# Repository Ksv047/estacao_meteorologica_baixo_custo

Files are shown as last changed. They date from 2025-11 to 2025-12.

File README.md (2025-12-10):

# 🌦️ Estação Meteorológica 3D de Baixo Custo – IFC Camboriú

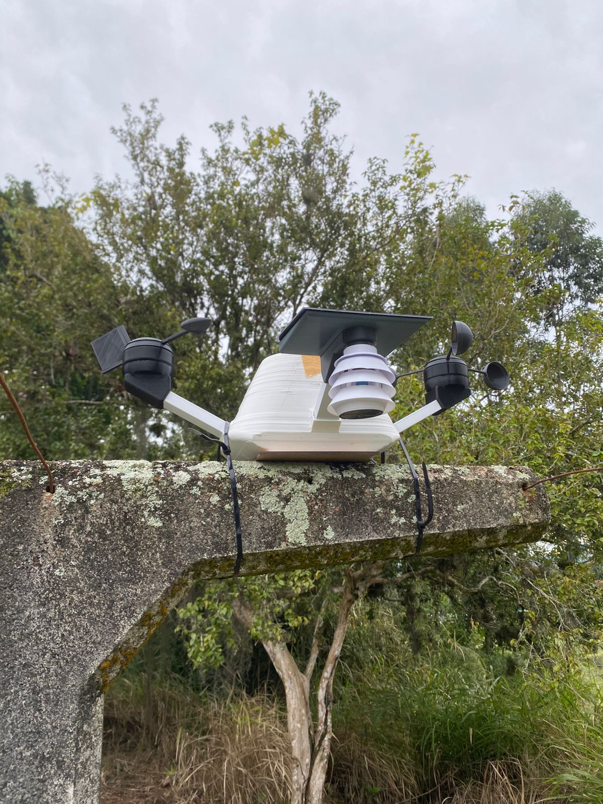
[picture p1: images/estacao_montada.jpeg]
Estação montada


##  Sobre o Projeto

Este projeto apresenta a **evolução de um protótipo de estação meteorológica de baixo custo**, desenvolvido no **Instituto Federal Catarinense - Campus Camboriú**, com o objetivo de funcionar de forma contínua em ambientes externos. 

A proposta é criar uma estação **acessível, precisa e replicável**, utilizando **impressão 3D**, **componentes eletrônicos de baixo custo** e **tecnologias IoT**, permitindo o monitoramento climático em tempo real.

---

##  Equipe de Desenvolvimento

- **Rafael Luiz C. Santos Pereira**
- **Cauã da Costa Silva**
- **Rafael de Moura Speroni** (Orientador)
- **Angelo Augusto Frozza** (Colaborador)
- **Joice Seleme Mota** (Colaboradora)

📍 *Instituto Federal Catarinense – Campus Camboriú*

---

## ⚙️ Componentes Principais

| Componente | Função |
|---|---|
| ESP32 | Microcontrolador principal |
| BME280 | Temperatura, umidade e pressão |
| AS5600 | Sensor de direção do vento |
| Reed Switch | Pluviômetro tipo báscula |
| Painel solar + bateria | Alimentação autônoma |
| PCB personalizada | Integra ESP32, sensores e monitoramento de carga |

---

##  Estrutura Física

A estrutura foi impressa em 3D e desenhada para:
- Resistir à chuva e ventos;
- Ser montada por encaixe e rosca;
- Reduzir o número de partes e o tempo de impressão;
- Permitir fixação em haste de suporte;

Arquivos STL disponíveis em [`3d_models`](hardware/3D_MODELS).

---

## 📡 Comunicação

A estação utiliza comunicação **Wi-Fi** para envio de dados ao **ThingsBoard** por meio de requisições HTTP.  
Futuramente, está prevista a integração com **LoRa (SX1278)**, visando maior alcance e menor consumo energético.

Mais informações em [`docs/comunicacao.md`](firmware/Thinsboard/thingsboard.http).

---

## 🧠 Firmware

O código-fonte está em [`firmware/src`](firmware/main/codigo_estacao.ino).

Funções principais:
- Leitura dos sensores (BME280, AS5600, reed switch);
- Cálculo de chuva e vento;
- Envio de dados via HTTP;
- Modo de sono para economia de energia (deepsleep).

---

## 📊 Exemplo de Dados

| Data | Temperatura (°C) | Umidade (%) | Pressão (hPa) | Chuva (mm) |
|---|---|---|---|---|
| 15/10/2025 10:00 | 27.3 | 68 | 1012 | 0.0 |
| 15/10/2025 11:00 | 28.1 | 66 | 1011 | 0.2 |

Mais exemplos em [`data/exemplos_medicoes.csv`](data/painel_thingsboard.png)

---

## 🤝 Contribuindo

Este projeto é de caráter **acadêmico e experimental**, parte da Feira de Iniciação Científica e Extensão (FICE 2025).  
Contribuições futuras são bem-vindas por meio de *pull requests* ou *issues*.

---

## 📸 Créditos

Projeto desenvolvido pelos alunos e professores do **IFC – Campus Camboriú**, no contexto do projeto *Plataforma georreferenciada VigiAA - Vigilância do Aedes Aegypti* (Edital FAPESC 37/2024).

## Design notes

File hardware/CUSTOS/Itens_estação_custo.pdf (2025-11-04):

A tabela a seguir apresenta o custo estimado para a confecção de uma estação meteorológica de baixo custo, conforme projeto desenvolvido no IFMaker, do IFC-Camboriú Os valores são estimados, uma vez que as estações desenvolvidas neste projeto ainda se encontram em fase de prototipação e ajustes. Além disso, os valores de alguns itens são estimados de acordo com a apresentação para compra.

Item | Descrição | Quantidade | Preço unitário | Preço total
Imã Neodinio Pequeno 2mm/3mm | Utilizado no anemômetro, pluviômetro, e sensor de direção do vento | 03 | R$ 0,20 | R$ 0,60
Reed Switch 14mm 2mm diam | Utilizado no anemômetro, pluviômetro, e sensor de direção do vento | 10 | R$ 2,00 | R$ 20,00
Eixo Metalico 6cm/0.5mm | Utilizado no anemômetro, pluviômetro, e sensor de direção do vento | 3 | R$ 9,00 | R$ 27,00
Rolamentos Mr85zz | Utilizado no anemômetro, pluviômetro, e sensor de direção do vento | 4 | R$ 6,80 | R$ 27,20
Conector Femea 2mm PHF4 03 vias | Fixação nas placas eletrônicas | 11 | R$ 0,20 | R$ 2,20
Conector Macho 2mm 90 - PHMN4 - 03 Vias | Conexão sensor/chicote/placa | 11 | R$ 0,51 | R$ 5,61
Fio Vermelho Awg24 | Chicotes Sensor/Interface | 3 | R$ 1,20 | R$ 3,60
Fio Amarelo Awg24 | Chicotes Sensor/Interface | 3 | R$ 1,20 | R$ 3,60
Fio Azul Awg24 | Chicotes Sensor/Interface | 3 | R$ 1,20 | R$ 3,60
Placa de prototipação de fenolite - 5x7cm | Placas eletrônicas e interfaces | 2 | R$ 3,00 | R$ 6,00
ESP32 Wifi DevKit1 | Microcontrolador | 1 | R$ 40,00 | R$ 40,00
Resistor 330r | Circuitos elétricos | 10 | R$ 0,14 | R$ 1,40
Resitor 200R | Circuitos elétricos | 1 | R$ 0,29 | R$ 0,29
Cabo par trançado UTP - metro | Circuitos elétricos | 1 | R$ 1,00 | R$ 1,00
18650 Battery Shield | Carregador de bateria | 1 | R$ 70,00 | R$ 70,00

Bateria 18650 3,7v’ | Alimentação | 2 | R$ 10,00 | R$ 20,00
Sensor BME280 | Sensor de pressão atmosférica | 1 | R$ 35,00 | R$ 35,00
Sensor DHT11 | Sensor de temperatura | 1 | R$ 18,00 | R$ 18,00
Filamento PLA 1,75mm | Impressão das partes estruturais da estação | 1 | R$ 100,00 | R$ 100,00

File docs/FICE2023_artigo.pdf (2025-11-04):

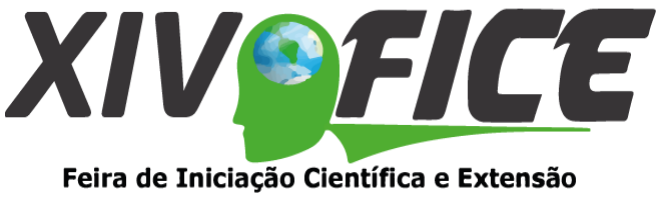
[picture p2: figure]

Desenvolvimento de uma estação meteorológica de baixo custo para mapeamento de microclima

Categoria Pesquisa
Trabalho em Andamento
Nível Graduação

Arthur Grandi¹

; Paulo Vinícius Kuss²

; Rafael Speroni³

; Daniel Anderle⁴

RESUMO

Santa Catarina é uma das regiões do Brasil mais propensas a enfrentar desastres naturais, como enchentes, deslizamentos de terra, ciclones extratropicais e até mesmo ocorrência de furacões. Dada essa vulnerabilidade, a previsão precisa do clima e o monitoramento do microclima tornam-se cada vez mais cruciais para garantir a segurança da população e reduzir os danos causados por esses eventos. O objetivo deste projeto de pesquisa é desenvolver uma estação meteorológica de baixo custo e de código aberto, que seja modular, escalável e capaz de medir indicadores de microclima. A intenção é criar uma ferramenta acessível e versátil para utilização em diversas aplicações, incluindo pesquisa científica, agricultura, monitoramento ambiental e prevenção de desastres naturais em Santa Catarina.

Palavras-chave: Estação Meteorológica; Desastres Naturais; Microclima; Baixo custo; Impressora 3D.

### 1. INTRODUÇÃO

O relatório conjunto da Universidade Federal de Santa Catarina (UFSC), Centro de Estudos e Pesquisas em Engenharia e Defesa Civil (CEPED) e Banco Mundial sobre danos materiais e prejuízos decorrentes de desastres naturais no Brasil entre 1995 e 2019 aponta que o país sofreu danos e prejuízos totais de 333,35 bilhões de reais nesse período, com uma média anual de 13,33 bilhões de reais. Santa Catarina é destacado como um estado sensível a esses desastres e aparece no topo das pesquisas em várias categorias.

De acordo com o Atlas de Desastres Naturais do Estado de Santa Catarina, entre 1980 e 2007, os dez municípios mais afetados pelo estado registraram diversos

4 Professor orientador, Instituto Federal Catarinense - Campus Camboriú, e-mail daniel.anderle@ifc.edu.br

3 Coordenador adjunto, Instituto Federal Catarinense - Campus Camboriú, e-mail rafael.speroni@ifc.edu.br

2 Estudante do curso BSI, Instituto Federal Catarinense - Campus Camboriú, e-mail paulov@kuss.com.br

1 Estudante do curso BSI, Instituto Federal Catarinense - Campus Camboriú, e-mail arthuragrandi@gmail.com eventos, como inundações graduais, inundações bruscas, escorregamentos, estiagens, granizos, vendavais, tornados e marés de tempestades. O Furacão Catarina foi um episódio inédito em 2004. Enchentes históricas em Tubarão e Blumenau causaram grandes prejuízos e impactos sociais. As enchentes em Santa Catarina frequentemente causam deslizamentos, como o ocorrido em 2008 no complexo do Morro do Baú, em Ilhota. Em 2011, as chuvas provocaram enchentes em cerca de 83 municípios, resultando em seis mortes e afetando quase 1 milhão de pessoas.

Em 2020, eventos meteorológicos extremos causaram perdas humanas e materiais em Santa Catarina, com o estado batendo recordes em números de eventos desse tipo. O relatório de danos materiais e prejuízos decorrentes de desastres naturais indica que o estado é o terceiro com mais registros de danos em ensino, totalizando um prejuízo de 163,9 milhões de reais. Em dezembro de 2022, fortes chuvas causaram alagamentos, deslizamentos e interditaram rodovias na Grande Florianópolis e outras regiões de SC, causando danos materiais e perda de vidas humanas e animais. A BR-376 foi bloqueada devido a um deslizamento de terra, isolando parcialmente o estado.

Esses desastres naturais têm ocasionado a destruição de edificações,
infraestruturas | públicas, | telecomunicações | e | danos | materiais | diversos,
representando risco à integridade física das pessoas nas áreas afetadas. O prejuízo acumulado em Santa Catarina já alcança 17,7 bilhões de reais, de acordo com o relatório de danos materiais e prejuízos decorrentes de desastres naturais. Nesse contexto, torna-se crucial estudar os microclimas e ampliar o número de estações meteorológicas como medida de redução de riscos.

O desenvolvimento de um protótipo de estação meteorológica modular de código aberto e baixo custo tem como objetivo coletar dados e medir indicadores do microclima. Os estudantes envolvidos no projeto terão a oportunidade de adquirir conhecimentos técnicos e tecnológicos, incluindo a coleta de dados e redação de artigos científicos. A integração do projeto ao Laboratório LabMaker do Campus Camboriú do IFC busca otimizar recursos e proporcionar novas oportunidades de ensino, pesquisa e extensão à comunidade acadêmica.(SANTA CATARINA e Relatório de danos materiais e prejuízos decorrentes de desastres naturais no Brasil)

### 2. PROCEDIMENTOS METODOLÓGICOS

A abordagem empregada é da pesquisa quantitativa onde a ideia é obter informações objetivas e mensuráveis, permitindo a análise estatística dos resultados para identificar padrões, relações e tendências. A pesquisa se caracteriza por uma pesquisa tecnológica, pois segundo Junior et. al(2014), o conhecimento científico, se propõe a desenvolver teorias de ampla aplicação, enquanto que o conhecimento tecnológico é responsável pelo desenvolvimento de teorias de aplicação extremamente restritas, com vistas à solução de problemas pontuais e na maioria das vezes isolados, mais voltados à inovação tecnológica.

O desenvolvimento das estações meteorológicas de baixo custo baseia-se na utilização de plataformas de hardware e softwares livres, além da utilização de componentes confeccionados em impressoras 3D. O desenvolvimento da estação meteorológica será alicerçado em uma metodologia colaborativa de projetos. Para tal implica na participação de todos os membros da equipe desde o planejamento até a execução, discutindo em grupo a viabilidade de cada uma das etapas da pesquisa.

Como ponto de partida deste projeto serão estudadas as plataformas de hardware livre Arduíno e Raspberry Pi, pois a utilização destas plataformas de forma independente ou interconectadas possibilitam a integração com diversos componentes de hardware, tais como LEDs, mostradores de matriz de pontos, botões, interruptores, motores, sensores de temperatura, pressão, de distância, de luminosidade, receptores GPS, módulos Ethernet ou qualquer outro dispositivo que emita dados ou possa ser controlado.

### 3. RESULTADOS E DISCUSSÃO

1) Climatologia

A climatologia estuda variáveis como temperatura, precipitação, vento, umidade, pressão atmosférica, radiação solar, entre outros, para compreender as condições climáticas de uma região. Além disso, a climatologia também investiga as causas das mudanças climáticas, incluindo os impactos humanos e naturais sobre o clima. A compreensão do clima é crucial para muitas atividades humanas, incluindo agricultura, gestão de recursos hídricos, prevenção de desastres naturais e planejamento urbano, entre outras.
Segundo Steinke(2016), entender a climatologia requer uma compreensão básica dos controles físicos do clima, essencialmente os fatores astronômicos e fatores terrestres que juntos determinam a natureza dos climas na terra ao longo do tempo. Os fatores são agentes causais que condicionam os elementos climáticos(radiação solar, temperatura do ar, umidade do ar, pressão atmosférica, velocidade e direção do vento, tipo e quantidade de precipitação. A atuação desses diversos fatores faz com que os elementos climáticos, e meteorológicos, variem no espaço e no tempo.

Ainda nesse contexto, podemos reduzir os climas, que ocupam grandes áreas, em partes menores. Na climatologia eles são denominados microclimas.

1.1 Microclima

O microclima é o clima local de uma área específica, que pode diferir do clima regional ou global. É influenciado por fatores como topografia, presença de corpos d' água, vegetação, material de construção, entre outros. O microclima é importante porque pode afetar a vida selvagem, a agricultura e a saúde humana.
Monteiro e Mendonça (2003) descrevem o microclima como a formação de condições climáticas na escala intra-urbana, derivadas diretamente da heterogeneidade, tanto do sítio, quanto da estruturação, morfologia e funcionalidades urbanas, gerando, paralelamente ao clima da cidade, bolsões climáticos intra-urbanos diferenciados, como ilhas de calor, topoclimas e microclimas.
Por isso, a medição precisa do microclima é importante para compreender as condições locais e como elas podem afetar a vida, a agricultura, as cidades e até mesmo a saúde humana.
2) Hardware

Segundo Da Silva et al.(2016), para construir uma estação meteorológica de baixo custo, é necessário selecionar hardware que seja acessível, confiável e capaz de realizar as medições necessárias. Alguns dos componentes comuns que podem ser usados incluem: Sensores: É necessário escolher sensores para medir as variáveis climáticas desejadas, como temperatura, umidade, pressão atmosférica, quantidade de precipitação, entre outros. Microcontrolador: Este componente é responsável por coletar e processar os dados dos sensores. Alguns microcontroladores populares para uso em projetos de baixo custo incluem o Arduino e o Raspberry Pi. Display: É importante ter uma forma de visualizar os dados coletados. Isso pode ser feito através de um display OLED ou um computador conectado à estação meteorológica. Bateria: Se a estação meteorológica for usada em locais remotos sem acesso à energia elétrica, é necessário incluir uma bateria para alimentar o sistema. Conectividade: Para transmitir os dados coletados, é necessário incluir uma forma de conectividade, como Wi-Fi ou rede celular.

3) Software

O uso de software livre é uma excelente opção para a construção de uma estação meteorológica de baixo custo, pois oferece vários benefícios, incluindo: Acessibilidade: Como o código-fonte está disponível publicamente, é possível acessá-lo e modificá-lo livremente, o que pode ser útil para personalizar a estação meteorológica para atender às necessidades específicas do projeto. Comunidade: Muitos projetos de software livre têm uma comunidade ativa de desenvolvedores e usuários, o que significa que há muitos recursos e soluções disponíveis para problemas comuns. Economia: Como o software livre é gratuito, pode ser uma ótima opção para projetos de baixo orçamento, onde é necessário minimizar os custos. Flexibilidade: Como o software livre é open-source, é possível modificá-lo para atender às necessidades específicas do projeto, o que é importante em projetos de estação meteorológica, onde é necessário medir variáveis climáticas específicas. Integração: O software livre pode ser facilmente integrado com outros componentes da estação meteorológica, como sensores, microcontroladores e displays.
Alguns exemplos de software livre que podem ser usados na construção de uma estação meteorológica de baixo custo incluem o OpenWeatherMap, o WeeWX e o PyOWM. A escolha exata do software dependerá das necessidades específicas do projeto e da experiência dos desenvolvedores.
4) Impressora 3D e as Estações Meteorológicas

Customização: As impressoras 3D permitem a impressão de peças personalizadas, o que é importante em projetos de estações meteorológicas, onde é necessário medir variáveis climáticas específicas. Redução de custos: Ao utilizar impressoras 3D, é possível reduzir os custos de fabricação de componentes, como suportes para sensores, caixas de proteção e outros componentes. Prototipagem rápida: As impressoras 3D permitem a produção de protótipos rapidamente, o que é importante no desenvolvimento de projetos de estações meteorológicas, onde é necessário testar e ajustar os componentes antes da construção final. Versatilidade: As impressoras 3D podem ser usadas para imprimir componentes de diferentes materiais, incluindo plásticos, resinas e metais, o que oferece muita flexibilidade na construção de componentes para a estação meteorológica. Acessibilidade: Com a popularidade das impressoras 3D, elas estão ficando cada vez mais acessíveis e fáceis de usar, o que significa que é possível imprimir componentes sem precisar de muita habilidade técnica.(DE JESUS QUEIROZ, MAURICIO e MATRAKAS,2019)

Em suma, as impressoras 3D podem ser uma ferramenta valiosa para a construção de um protótipo de uma estação meteorológica de baixo custo, pois permitem a produção de componentes personalizados, a redução de custos, a prototipagem rápida, a versatilidade e a acessibilidade

5) Resultados Parciais.

Com base no intuito de ser um projeto de baixo custo, os componentes da estação responsáveis pelas medições e análises climáticas foram selecionados de fontes abertas em plataformas de compartilhamento de projetos e produzidas nas impressoras 3D do IF Maker.

Com essa etapa concluída partimos para a seleção de qual microcontrolador será utilizado na estação meteorológica. Estudos foram feitos comparando a praticidade do arduino mega que não possui conexão wifi acoplada ao do esp 32 que conta com módulo wifi. Fica evidente além do custo mais baixo do esp 32 a praticidade que ele fornece ao possibilitar uma conexão direta a rede wifi.

Os testes seguirão para confirmar aspectos de outros componentes do projeto até que após a conclusão dos testes o protótipo seja finalizado, permitindo seguir para as análises comparativas entre custo benefício e eficiência da nossa estação e das estações comerciais.

6) Resultados Esperados

Desenvolver o protótipo de uma estação meteorológica modular de código aberto de baixo custo, para coleta de dados e medição de indicadores do microclima.

- Desenvolver o protótipo de um estação meteorológica utilizando componentes eletrônicos de baixo custo e partes desenvolvidas em uma impressora 3D do laboratório IFMaker do IFC - Campus Camboriú;
- Desenvolver uma aplicação para medir temperatura, umidade relativa do ar, pressão atmosférica, velocidade do vento e precipitação pluviométrica;
- Desenvolver um sistema para coleta dos dados meteorológicos de forma automatizada;
- Testar a viabilidade técnica da estação meteorológica através de testes e comparações com estações meteorológicas já aferidas;
- Comparar o custo do protótipo desenvolvido com estações meteorológicas comerciais;

### 4. CONSIDERAÇÕES FINAIS

Com o projeto intuímos trazer a educação climática para dentro das escolas de forma prática, ensinando os jovens a necessidade de estarem atentos às mudanças climáticas na sua região para a segurança de suas famílias e suas comunidades. Esse acesso também abre oportunidades de educação e integração no mundo da tecnologia por demonstrar a conexão entre a análise de dados, os sistemas de informação e a vida cotidiana.

Unificando os estudos, os testes e toda a pesquisa realizada, identificou-se uma lacuna para o crescimento da cobertura meteorológica no brasil e principalmente nos estados que são mais vulneráveis a catástrofes climáticas. A pesquisa tecnológica visa a implementação de uma solução para um problema específico. Nosso alvo, o problema das perdas humanas e materiais causados pela devastação de desastres climáticos e ambientais. O aumento no número de estações meteorológicas têm o potencial de preparar o poder público e a população para potenciais desastres, diminuindo os riscos à vida humana. Importante salientar que através do estudo dos microclimas será possível planejar o crescimento seguro da área urbana, impedindo a formação das ilhas de calor, reduzindo a quantidade da população que vive em áreas com risco de enchente, dentre outras formas de prevenção que um planejamento urbano e climático pode proporcionar.

### 5. REFERÊNCIAS

DA SILVA, Angelo Cesar Mendes, et al. ESTAÇÃO METEOROLÓGICA AUTOMÁTICA DE BAIXO CUSTO-Low Cost Automatic Meteorological Station. Multiverso: Revista Eletrônica do Campus Juiz de Fora-IF Sudeste MG, 2016, 1.1: 46-56.

DE JESUS QUEIROZ, Leonardo; MAURICIO, Claudio Roberto Marquetto; MATRAKAS, Miguel Diogenes. Construção de uma impressora 3D: Projetos abertos de baixo custo e possibilidades da aplicação na educação. 2019.

EPAGRI -Empresa de Pesquisa Agropecuária e Extensão Rural de Santa Catarina . Eventos meteorológicos bateram recordes em Santa Catarina em 2020. Disponível em:
<https://www.epagri.sc.gov.br/index.php/2021/01/27/eventos-meteorologicos-bateram-recordes-em-santa-catarina-em-2020/>. Acesso em: 12 dez. 2022.

FREITAS JUNIOR, Vanderlei., et al. A pesquisa científica e tecnológica. Revista Espacios, vol. 35, nº 9, 2014. Disponível em: https://www.revistaespacios.com/a14v35n09/14350913.html. Acesso em: 04 de setembro de 2023.

IBGE - Instituto Brasileiro de Geografia e Estatística. Cidades e Estados. Disponível em: <https://www.ibge.gov.br/cidades-e-estados/sc.html>. Acesso em: 12 dez. 2022.

MONTEIRO, C. A. F.; MENDONÇA, F. (org.) Clima urbano. 2ª edição, São Paulo: Contexto, 2015. 191p

Relatório de danos materiais e prejuízos decorrentes de desastres naturais no Brasil : 1995 – 2019 / Banco Mundial. Global Facility for Disaster Reduction and Recovery. Fundação de Amparo à Pesquisa e Extensão Universitária. Centro de Estudos e Pesquisas em Engenharia e Defesa Civil. [Organização Rafael Schadeck] – 2. ed. – Florianópolis: FAPEU, 2020. 156 p. : il. color.; 30 cm.

SANTA CATARINA. Atlas de desastres naturais do estado de santa catarina: período de 1980 a 2010. IHGSC/Cadernos Geográficos, 2014, 2.

STEINKE, Ercília Torres. Climatologia fácil. Oficina de Textos, 2016.

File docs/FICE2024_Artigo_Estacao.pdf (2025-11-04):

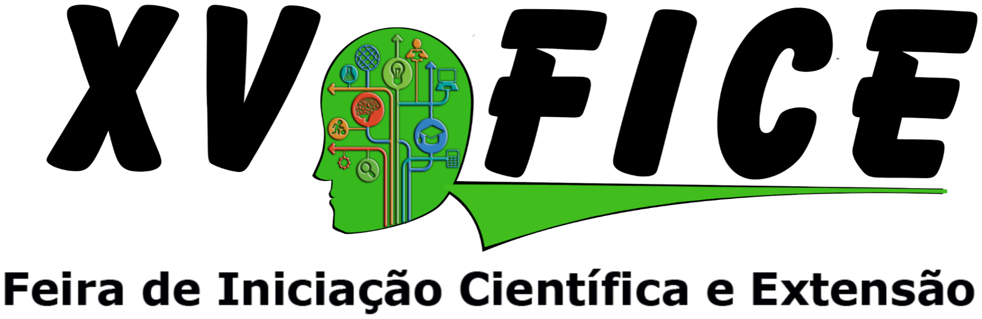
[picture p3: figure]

Desenvolvimento de uma Estação Meteorológica de Baixo Custo - Fase II

Categoria: Pesquisa
Trabalho: Trabalho em Andamento Nível: Graduação

Rafael Luiz C. Santos Pereira¹

; Paulo Vinícius Kuss²
; Rafael de Moura
Speroni³Daniel Fernando Anderle⁴

RESUMO

O trabalho descreve a segunda fase do projeto que tem por finalidade o desenvolvimento de uma estação meteorológica de baixo custo, caracterizada como um dispositivo de internet das coisas (IoT). Tendo como ponto de partida um protótipo desenvolvido com projeto de código aberto, a segunda fase tem por objetivo a otimização das estruturas, visando ao projeto e construção de um equipamento mais compacto, bem como da substituição de circuitos e componentes eletrônicos. Por meio da comparação com uma solução comercial, identificou-se a necessidade de alterações em componentes de hardware, bem como de ajustes nos códigos-fonte responsáveis pela coleta e envio dos dados. Atualmente, encontra-se em fase de construção do segundo protótipo, já incluindo as melhorias.

Palavras-chave: estação meteorológica; internet das coisas; clima.

### 1. INTRODUÇÃO

Segundo o Atlas Digital de Desastres no Brasil (Brasil, 2023), no ano de 2023, o estado de Santa Catarina registrou 386 ocorrências de eventos climáticos extremos, resultando em graves consequências. Esses eventos afetaram diretamente 1.346.345 pessoas, deixando 98.428 desabrigados e desalojados. Os danos materiais foram avaliados em R$1.6 Bi, enquanto os prejuízos totais atingiram a cifra de R$3.48 Bi, além de resultar em 10 óbitos. Esses eventos, classificados como de origem hidrológica (inundações, alagamentos, enchentes, deslizamentos) e meteorológica (raios, ciclones, tornados, vendavais), evidenciam a vulnerabilidade da região frente aos eventos climáticos extremos.
Diante desse cenário torna-se evidente, a importância de uma rede de estações meteorológicas conectadas e inteligentes para a prevenção e o alerta antecipado que potencialmente podem salvar vidas e minimizar os riscos de perdas humanas e materiais. Nos últimos 10 anos, Santa Catarina registrou 32 óbitos decorrentes de eventos climáticos de origem hidrológica, conforme indicado pelo Atlas Digital de Desastres no Brasil (Brasil, 2023).
A Internet das Coisas (IoT) é um conceito que ainda está em evolução, sem uma definição fixa e amplamente aceita. Segundo Mouha (2021), a IoT continua a

4 Professor orientador, IFC Camboriú, daniel.anderle@ifc.edu.br

3 Professor orientador, IFC Camboriú, rafael.speroni@ifc.edu.br

2 Estudante do curso BSI, Instituto Federal Catarinense - Campus Camboriú, e-mail pviniks@gmail.com

1 Estudante do curso de Bacharelado em Sistemas de Informação, IFC Camboriú, rafaelluizcc@gmail.com -bolsista - Edital 12/2024 amadurecer, sendo um dos conceitos mais novos e populares no mundo da tecnologia da informação. A essência da IoT está na ideia de "coisas" — qualquer dispositivo equipado com sensores embutidos, capaz de coletar dados e transmiti-los por meio de redes sem a necessidade de intervenção humana. A tecnologia incorporada nesses dispositivos permite que eles interajam tanto com seu estado interno quanto com o ambiente externo, auxiliando no processo de tomada de decisões.
Nesse contexto, a tecnologia IoT tem o potencial de desempenhar um papel vital na prevenção de perdas humanas durante desastres. Ao utilizar estações meteorológicas de baixo custo conectadas, a tecnologia IoT pode ajudar a prever situações de risco analisando a meteorologia e em casos de risco, emitindo alertas antecipados, possibilitando uma resposta rápida e eficaz para minimizar os impactos de eventos climáticos extremos. Assim, a tecnologia pode ser uma aliada poderosa na mitigação de desastres, salvando vidas e reduzindo prejuízos.
A implantação de uma estação meteorológica oferece diversas vantagens, mas um dos obstáculos à sua popularização e uso em larga escala é o custo. As alternativas mais baratas de estações meteorológicas comerciais têm seu preço aproximado iniciando em R$2.500,00⁵
, enquanto que o custo estimado para a fabricação deste protótipo, é de aproximadamente R$440,00. O desenvolvimento de uma estação meteorológica de baixo custo no campus IFC Camboriú⁶ é benéfico para toda a comunidade do Instituto Federal, pois promove a criação de uma tecnologia acessível com múltiplas aplicações, desde o uso agrícola até a prevenção de desastres naturais.
As tecnologias open source foram essenciais no desenvolvimento da estação meteorológica de baixo custo. Essa tecnologia permite que usuários modifiquem e adaptem ferramentas sem custos, oferecendo flexibilidade e acessibilidade no desenvolvimento. Um exemplo é a tecnologia da placa ESP32, de hardware aberto. A natureza open source dessas ferramentas acelerou o progresso do projeto, permitindo o uso de diversos recursos sem restrições financeiras.
No trabalho anterior, intitulado "Desenvolvimento de uma Estação Meteorológica de Baixo Custo para Mapeamento de Microclima" (Grandi et al., 2023), foi discutido o desenvolvimento de um protótipo para demonstração da tecnologia e para estudos de viabilidade. Com o avanço desse projeto, na segunda versão, está em desenvolvimento uma estação meteorológica independente com estrutura compacta, capaz de ser instalada em ambientes externos. Este novo modelo visa oferecer um baixo custo, mas com funcionalidades semelhantes às das estações meteorológicas comerciais, proporcionando uma solução prática e acessível para o monitoramento climático.

### 2. PROCEDIMENTOS METODOLÓGICOS

Para o desenvolvimento do trabalho está sendo realizada a pesquisa bibliográfica, segundo a qual se faz a revisão da literatura relacionada à temática. Nesta abordagem, a resolução de um problema é buscada por meio da análise dos referenciais teóricos e suas contribuições (Boccato, 2006).
A pesquisa se caracteriza como Tecnológica (Freitas Júnior et. al, 2014), uma vez que o conhecimento tecnológico é responsável pelo desenvolvimento de teorias de aplicação extremamente restritas, com vistas à solução de problemas pontuais e

6 Projeto aprovado no Edital 12/2024 – Apoio a Projetos de Pesquisa no Laboratório IFMaker

5 Pesquisa de preço realizada em sites no Brasil.

na maioria das vezes isolados, mais voltados à inovação tecnológica. Para Cupani (2006), o conhecimento tecnológico, estando dirigido a uma tarefa específica, tem como resultado tipos de soluções para determinadas aplicações.
A revisão de literatura ocorre em paralelo com as demais etapas do projeto, em função da necessidade de compreensão de conceitos e da identificação de técnicas específicas a serem utilizadas.
Partiu-se de um primeiro protótipo, desenvolvido na edição anterior do projeto (Grandi et al., 2023), cujas peças estruturais foram impressas em impressoras 3D, a partir de projeto de código aberto (Ward, 2018), e o módulo eletrônico foi baseado em uma placa ESP32, um conjunto de microprocessadores de baixo custo, compatível com diversos tipos de sensores.
A etapa seguinte teve por objetivo integrar o protótipo desenvolvido com um serviço de coleta, armazenamento e visualização de dados⁷
. Para tal, utilizou-se o
servidor de IoT Thingsboard (2024), disponível na infraestrutura do IFMaker do IFC-Camboriú. Este servidor conta com uma lnterface de Programação de Aplicação (API) Restful, e os dados são enviados pela estação meteorológica por meio de requisições HTTP.
Visando à identificação das necessidades de melhorias na estação projetada, as medidas coletadas a partir dos sensores do protótipo foram comparadas com as medidas obtidas pela estação meteorológica do Curso Técnico em Defesa Civil do IFC-Camboriú⁸
, que trata-se de um modelo comercial. A partir desta comparação, identificou-se uma inconsistência nos cálculos do pluviômetro e do anemômetro, para os quais se buscou a correção.
Visando aos ajustes de medidas, passou-se à alteração de componentes estruturais da estação. Assim, projetou-se uma nova versão para o chassi principal, mais compacta, e que permita uma melhor fixação em uma haste. Além disso, houve necessidade de reprojetar o anemômetro, uma vez que o primeiro modelo estava pouco sensível. Foram feitos os desenhos técnicos auxiliados por computador, com a posterior modelagem 3D e exportação para formato compatível com as impressoras 3D.
Atualmente, ainda está em desenvolvimento a nova versão do anemômetro, bem como busca-se otimizar a solução da alimentação da estação, com o uso de painéis de energia solar e baterias. O objetivo é garantir a autonomia do equipamento, de forma que seja capaz de funcionar de forma ininterrupta.
A próxima seção descreve em mais detalhes os componentes da estação, além de apresentar alguns dos artefatos gerados no processo de desenho técnico e modelagem do novo protótipo.

### 3. RESULTADOS E DISCUSSÃO

O protótipo resultante da Fase 1 do projeto tem uma estrutura cuja finalidade era possibilitar a demonstração dos componentes, e o circuito eletrônico foi montado de maneira provisória, utilizando-se uma placa de ensaio (protoboard), conforme foto apresentada na figura 1.

8 Painel da Estação Meteorológica do TDC: https://ambientweather.net/dashboard/60a4f7e92df2960cb08d2a92a3607a94

7Painel de visualização das medidas da Estação desenvolvida: https://abre.ai/estacaoifmaker

Figura 1 - Estação Meteorológica: Protótipo da Fase 1 do projeto

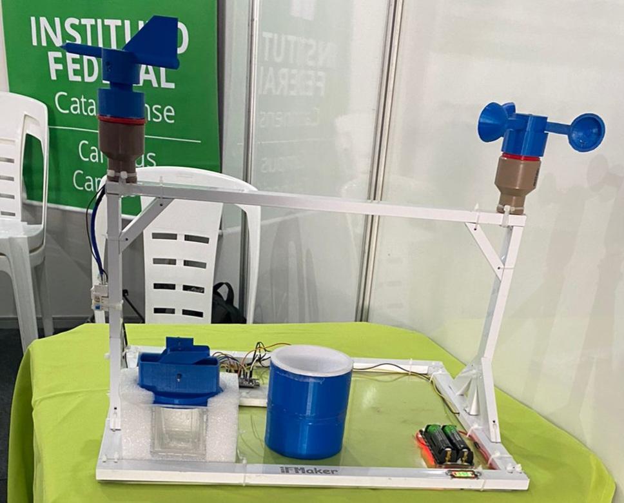
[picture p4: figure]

Fonte: Elaborado pelos autores
O funcionamento do pluviômetro é baseado no princípio de medição de volume coletado. Conforme a água da chuva desce por um funil, ela é direcionada para a báscula, que funciona como uma pequena balança. Quando a báscula atinge um determinado volume de água, seu peso faz com que ela incline, o movimento é detectado por um sensor, (Mansano et al., 2015, p. 19) a precipitação é contabilizada contando o número de interações do sensor, após, os dados do sensores então são processados pela placa principal, que envia os valores para o servidor.

Figura 2 - Desenho Técnico do Pluviômetro de Báscula.

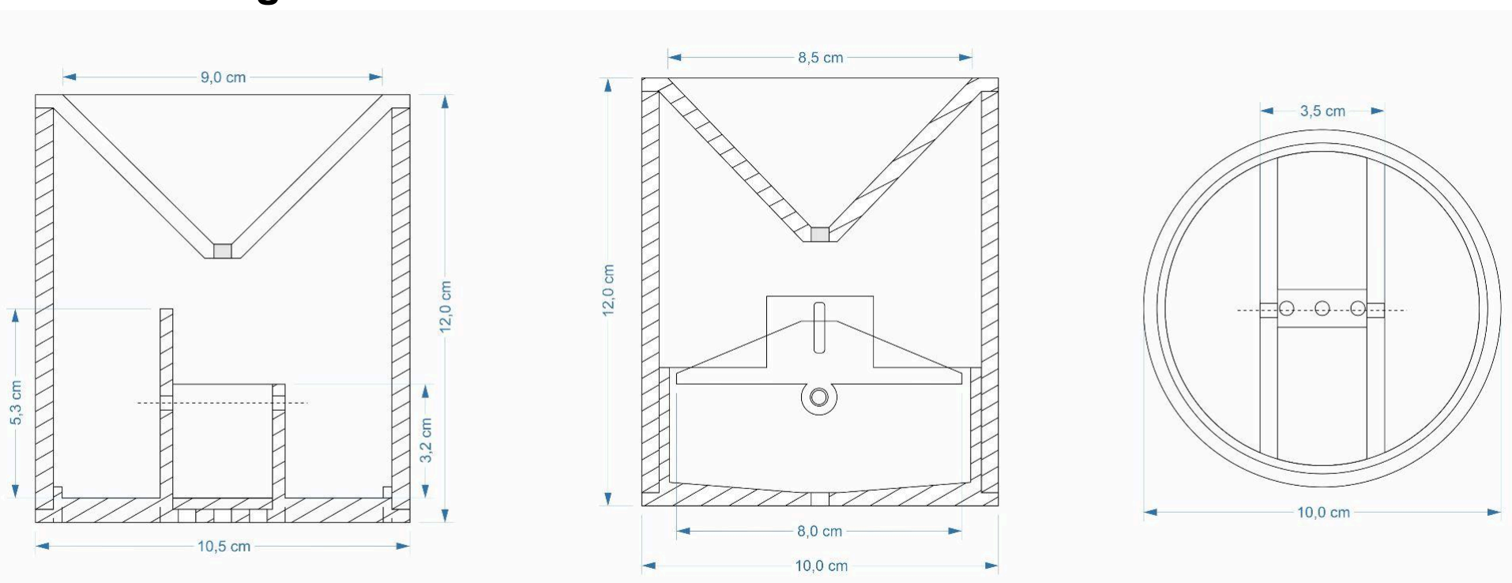
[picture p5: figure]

Fonte: Elaborado pelos autores
A Figura 2 apresenta um desenho técnico do pluviômetro, no desenho estão dispostos respectivamente, a vista lateral em corte, a vista frontal em corte, e a vista superior do pluviômetro.
O anemômetro, sensor para medir a velocidade do vento, utiliza uma hélice anemométrica conectada a um eixo metálico, que é suportado por dois rolamentos, fixos a uma base, onde está posicionado um sensor magnético (reed switch). Na estrutura da hélice foi acoplado um ímã de neodímio. Conforme a hélice gira com a força do vento, o ímã passa pelo reed switch, gerando pulsos elétricos. O sistema, então, contabiliza o número de pulsos emitidos em um determinado período, permitindo o cálculo da velocidade do vento.
Já o anemógrafo, que está montado em uma estrutura semelhante à do anemômetro, conta com uma peça móvel que muda de posição, conforme a direção do vento. A peça possui um ímã de neodímio que, ao girar, passa por 8 sensores magnéticos (reed switches), dispostos ao redor do sensor. Cada um destes sensores corresponde a um dos pontos cardeais (Norte, Sul, Leste, Oeste) e colaterais (Nordeste, Noroeste, Sudeste, Sudoeste), são acionados a depender da posição em que o ímã se encontra, gerando um sinal elétrico.
Para a medição de temperatura (termômetro) e umidade (higrômetro), o sensor escolhido foi o DHT11. Trata-se de um sensor amplamente utilizado em projetos de monitoramento ambiental devido à sua confiabilidade, simplicidade de uso, e baixo custo, e cujo princípio de funcionamento baseia-se em um termistor e um sensor capacitivo. As medidas deste sensor podem ser coletadas diretamente, sem a necessidade de cálculo ou transformação.

Figura 3 - Esquema eletrônico da Estação Meteorológica

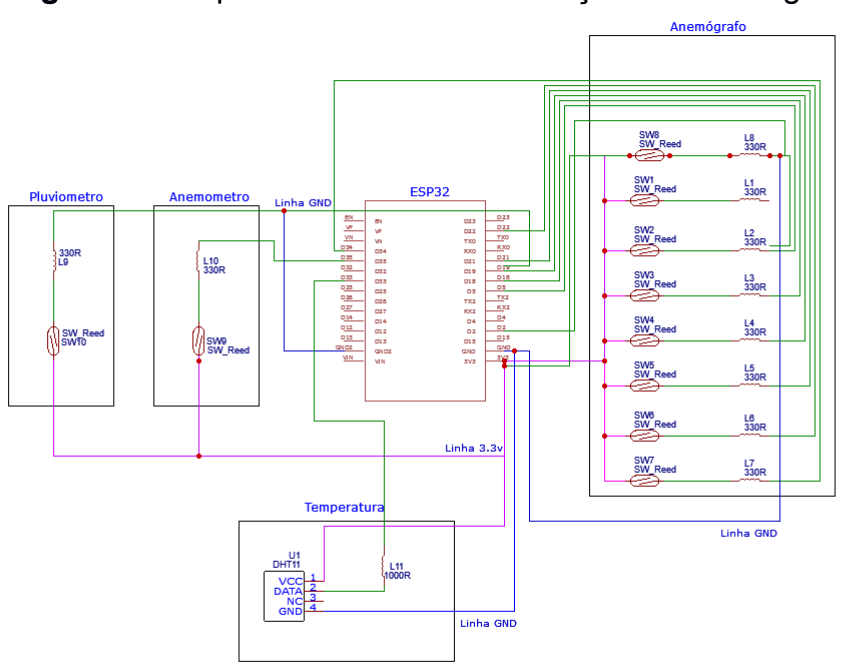
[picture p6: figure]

Fonte: Elaborado pelos autores
Na Figura 3 é apresentado o esquema elétrico da estação, a partir do diagrama eletrônico elaborado, foi desenvolvido um novo protótipo de placa eletrônica, visando à diminuição do espaço ocupado, e a utilização de conectores padronizados. Todos os componentes foram soldados em uma placa de prototipagem de 5x7cm.

Figura 4 - Estação Meteorológica: Protótipo da Fase 1 do projeto

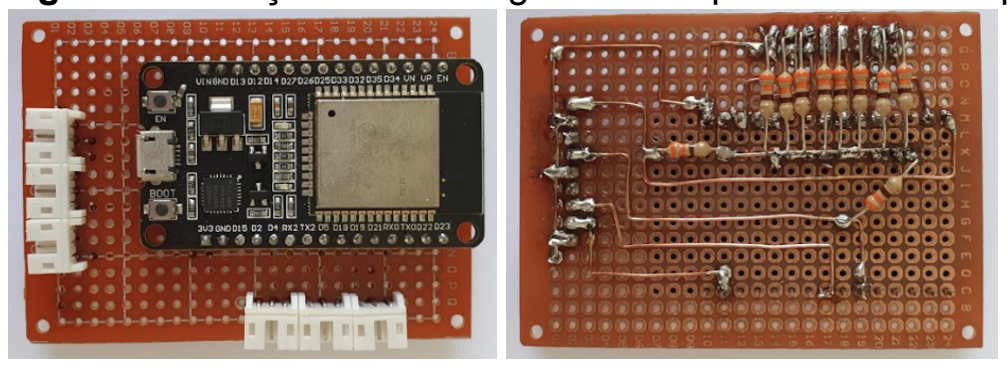
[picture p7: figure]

Fonte: Elaborado pelos autores

A Figura 4 apresenta o novo protótipo de placa eletrônica, onde é possível observar, na parte superior, a placa ESP32 e os conectores. Na parte inferior, estão localizados os resistores e fios que servem de trilhas.
A utilização de conectores justifica-se pela modularidade, de forma que cada sensor foi munido de um chicote de fios e conectores, podendo ser facilmente substituído, se necessário.
As medidas coletadas são transformadas em um conjunto de dados em formato JSON, que é enviado em uma requisição HTTP para a API do servidor de IoT. Dessa forma, os dados são agregados em um painel, que conta com diferentes gráficos e tabelas.

Figura 5 - Painel de visualização dos dados da estação meteorológica

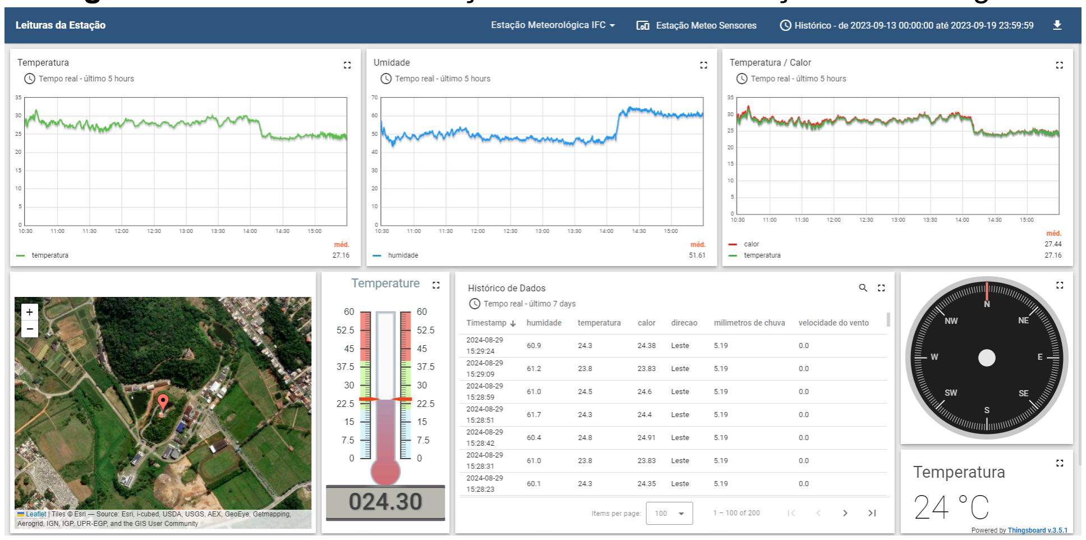
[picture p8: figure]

Fonte: Elaborado pelos autores

A Figura 5 apresenta uma captura de tela do painel de visualização das informações da estação meteorológica. Cabe salientar que, este painel é facilmente replicável para cada nova unidade de estação meteorológica que venha a ser construída, podendo-se gerar um conjunto de dados relevantes para o estudo do microclima.

### 4. CONSIDERAÇÕES FINAIS

Eventos climáticos extremos têm acontecido no mundo todo, e com frequência cada vez maior. O estado de Santa Catarina não é diferente, e vem experienciando importantes impactos sociais e econômicos, decorrentes destes eventos. Por isso, o monitoramento do clima mostra-se uma importante ferramenta na mitigação de impactos e na informação e conscientização da população.
Neste projeto, a proposta de desenvolvimento de uma estação meteorológica de baixo custo não busca competir com modelos comerciais. Antes disso, deseja-se demonstrar a viabilidade do desenvolvimento de um modelo replicável, com potencial educacional. Utilizando tecnologias de código aberto, e com a disponibilização do projeto completo, tanto sua confecção quanto a observação dos dados coletados podem ser objetos de estudo em escolas.
Ainda que o novo protótipo esteja em desenvolvimento, já é possível identificar avanços em relação à primeira fase do projeto. Desde a identificação de necessidades de melhorias em componentes do hardware impresso em 3D, passando por modificações no esquema eletrônico, até a adoção de um serviço de coleta e visualização de dados, que poderá ser utilizado por outros projetos de IoT do IFMaker.

### 5. REFERÊNCIAS

ARDUINO. About Arduino. Arduino, 2024. Disponível em: https://www.arduino.cc/en/about. Acesso em: 31 ago. 2024.

BRASIL. Ministério da Integração e do Desenvolvimento Regional. Secretaria de Proteção e Defesa Civil. Universidade Federal de Santa Catarina. Centro de Estudos e Pesquisas em Engenharia e Defesa Civil. Atlas Digital de Desastres no Brasil. Brasília: MIDR, 2023.

BOCCATO, V. R. C. Metodologia da pesquisa bibliográfica na área odontológica e o artigo científico como forma de comunicação. Revista de Odontologia da Universidade Cidade de São Paulo, São Paulo, v. 18, n. 3, p. 265-274, 2006. Disponível em
https://arquivos.cruzeirodosuleducacional.edu.br/principal/old/revista_odontologia/pdf/setembro_dezembro_2006/metodologia_pesquisa_bibliografica.pdf (https://arquivos.cruzeirodosuleducacional.edu.br/principal/old/revista_odontologia/pdf/setembro_dezembro_2006/metodologia_pesquisa_bibliografica.pdf) Acesso em 25 ago. 2024.

CUPANI, Alberto. La peculiaridad del conocimiento tecnológico. ScientiaeStudia, São Paulo, v. 4, n. 3, p. 353-71, 2006. Disponível em: http://www.scielo.br/pdf/ss/v4n3/a01v4n3.pdf. Acesso em: 06 abr. 2012.

FREITAS JUNIOR, Vanderlei., et al. A pesquisa científica e tecnológica. Revista Espacios, vol. 35, no 9, 2014. Disponível em: https://www.revistaespacios.com/a14v35n09/14350913.html. Acesso em: 25 ago. 2023.

GRANDI, Arthur; KUSS, Paulo Vinícius; SPERONI, Rafael de Moura; ANDERLE, Daniel Fernando. Desenvolvimento de uma Estação Meteorológica de Baixo Custo para Mapeamento de Microclima. In: FICE 2023, Camboriú. Anais Eletrônicos [...] Camboriú: IFC-Camboriú, 2024. Disponível em: https://publicacoes.ifc.edu.br/index.php/fice/issue/view/134. Acesso em 25 ago. 2024.

MANSANO, Matheus Veiga et al. Calibração de Pluviômetros de Báscula: Metodologia para análise e correção de dados de campo - Calibration of Tipping Bucket Rainfall Gauges: A methodology for field data analysis and correction. In: XV Safety, Health and Environment World Congress; jul. 2015. p. 19-22.

MOUHA, Radouan Ait Radouan Ait et al. Internet of things (IoT). Journal of Data Analysis and Information Processing, v. 9, n. 02, p. 77, 2021.
THINGSBOARD. ThingsBoard - Open Source IoT Platform. c2024. Página inicial. Disponível em: https://thingsboard.io. Acesso em 27 ago. 2024.

WARD, Rob. LTB Weather Station. Thinginverse. 2018. Disponível em: https://www.thingiverse.com/thing:2849562. Acesso em 27 ago. 2024.

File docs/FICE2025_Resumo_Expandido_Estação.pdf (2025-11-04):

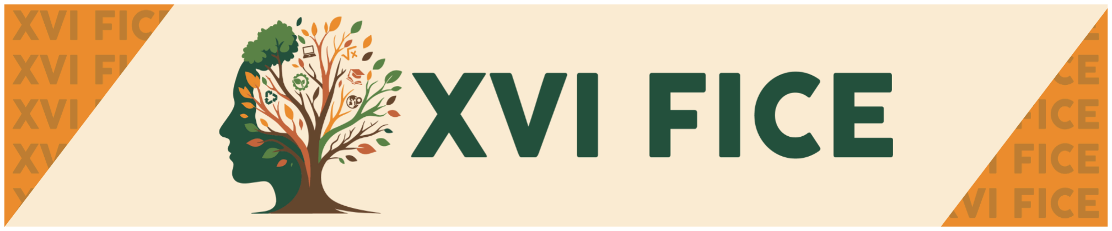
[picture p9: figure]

ESTAÇÃO METEOROLÓGICA DE BAIXO CUSTO: Resultados e desafios

Categoria: Pesquisa
Trabalho: Trabalho em Andamento Nível: Graduação

Rafael Luiz C. Santos Pereira¹

, Cauã da Costa Silva²

, Rafael de Moura Speroni³ ,
Angelo Augusto Frozza⁴

, Joice Seleme Mota⁵

RESUMO

Este trabalho apresenta a evolução de um protótipo de estação meteorológica de baixo custo desenvolvido para funcionar de forma contínua em ambientes externos. O estudo partiu de uma versão inicial e focou em aprimorar o protótipo melhorando a parte física e eletrônica. Comparações com estações meteorológicas comerciais revelaram inconsistências no sensor de chuva, o que impulsionou um redesenho da arquitetura do protótipo. A nova versão incorpora um sistema de energia solar que assegura autonomia ininterrupta, sensores mais precisos capazes de medir pressão atmosférica, temperatura, umidade, precipitação, velocidade e direção do vento e um novo código fonte. Os resultados preliminares demonstram avanços significativos comparados ao modelo anterior, com melhorias notáveis na precisão e robustez, o que garante maior confiabilidade nos dados coletados. Como perspectivas futuras busca-se aprimorar a comunicação entre os dispositivos por meio da implementação da tecnologia LoRa, visando maior eficiência e alcance. Adicionalmente, a otimização do design a tornará mais acessível para diversas aplicações no monitoramento climático.
Palavras-chave: estação meteorológica; (IoT); clima; LoRa;

### 1. INTRODUÇÃO

Segundo dados do Atlas Digital de Desastres no Brasil (Brasil, 2025) em 2024 a região sul do Brasil sofreu com eventos classificados como de origem hidrológica (inundações, alagamentos, enchentes, deslizamentos) que deixaram 189 mortos e 805.270 pessoas desabrigadas ou desalojadas. Segundo o Conselho Permanente de Agrometeorologia Aplicada do Estado do Rio Grande do Sul (COPAAERGS, 2024), no período de 27 de abril a 2 de maio (6 dias), em muitas cidades do Rio Grande do Sul, a precipitação registrada foi entre 300 e 400 mm e, em outras, os valores atingiram 500 a 700 mm, o que corresponde a um terço da média histórica de precipitação anual.
A utilização de estações meteorológicas de baixo custo baseadas em conceitos da Internet das Coisas (IoT) surge como alternativa viável para ampliar o

5 Professor colaborador, IFC Camboriú, joice.mota@ifc.edu.br

4 Professor colaborador, IFC Camboriú, | angelo.frozza@ifc.edu.br
3 Professor orientador, IFC Camboriú, | rafael.speroni@ifc.edu.br

2 Estudante do curso Bacharelado em Sistemas de informação, IFC Camboriú, caua.silva.ifc@gmail.com

1 Estudante do curso Bacharelado em Sistemas de informação, IFC Camboriú, rafaelluizcc@gmail.com alcance do monitoramento, além de ser uma solução que pode ter impacto em outras áreas. Para Freitas (2025, p. 15), o desenvolvimento de estações meteorológicas de baixo custo permite que pequenos produtores rurais, pesquisadores e demais interessados nos estudos climatológicos tenham acesso a sistemas de coleta e uso desses dados.
A Internet das Coisas (IoT) é um conceito em evolução, segundo Bruno P. Santos et al. (2016) a Internet das Coisas, em poucas palavras, nada mais é que uma extensão da Internet atual, que proporciona aos objetos do dia-a-dia com capacidade computacional e de comunicação se conectarem à Internet. Segundo Mouha (2021) a IoT continua a amadurecer, sendo um dos conceitos mais novos e populares no mundo da tecnologia da informação. Esse conceito aplicado à meteorologia possibilita o desenvolvimento de sistemas distribuídos e interconectados que coletam, processam e transmitem dados ambientais em tempo real, fornecendo informações essenciais para ações de resposta rápida e planejamento preventivo em casos de desastres.
Em ambientes urbanos e industriais o monitoramento ambiental é crucial para a gestão de recursos e a proteção da saúde pública. Como destacam Gonçalves, Freitas e Jesus (2024), estações meteorológicas de baixo custo integradas a sistemas IoT permitem a coleta de dados meteorológicos, contribuindo para a avaliação de riscos e o planejamento urbano sustentável. A viabilidade dessas soluções acessíveis é fundamental para o monitoramento em larga escala, especialmente em áreas onde equipamentos de alto custo são inviáveis.
No trabalho anterior, intitulado “Desenvolvimento de uma Estação Meteorológica de Baixo Custo – Fase II” (PEREIRA et al., 2024), foi discutido o início do desenvolvimento, falando a respeito do processo de design dos componentes e requisitos que a estação deveria ter. Neste trabalho apresentamos uma evolução do protótipo de estação meteorológica, corrigindo problemas de hardware e software. Este modelo visa oferecer uma estação meteorológica de baixo custo, compacta e com funcionalidades semelhantes às das estações meteorológicas comerciais, proporcionando uma solução prática, acessível e replicável para o monitoramento climático.

### 2. PROCEDIMENTOS METODOLÓGICOS

Para o desenvolvimento do trabalho está sendo realizada a pesquisa bibliográfica, segundo a qual se faz a revisão da literatura relacionada à temática. Nesta abordagem, a resolução de um problema é buscada por meio da análise dos referenciais teóricos e suas contribuições (BOCCATO, 2006).
A pesquisa se caracteriza como Tecnológica (FREITAS JÚNIOR et. al, 2014), uma vez que o conhecimento tecnológico é responsável pelo desenvolvimento de teorias de aplicação extremamente restritas, com vistas à solução de problemas pontuais e na maioria das vezes isolados, mais voltados à inovação tecnológica. Para Cupani (2006), o conhecimento tecnológico, estando dirigido a uma tarefa específica, tem como resultado tipos de soluções para determinadas aplicações.
A revisão de literatura ocorre em paralelo às demais etapas do projeto em função da necessidade de compreender conceitos e identificar técnicas específicas a serem utilizadas. Este trabalho tem como base trabalho de (PEREIRA et al., 2024), que serviu de ponto de partida para os aprimoramentos aqui descritos.
Nessa etapa tivemos como objetivo desenvolver e testar o protótipo da estação meteorológica, que operou em ambientes externos realizando a coleta e envio dos dados. Para o armazenamento e visualização dos dados foi utilizado o servidor de IoT Thingsboard (2024) disponível na infraestrutura do IFMaker do IFC-Camboriú. Esse servidor conta com uma Interface de Programação de Aplicação (API) Restful, para a qual os dados são enviados pela estação por meio de requisições HTTP.
Visando a identificação das necessidades de melhorias na estação projetada, as medidas coletadas pelo protótipo foram comparadas com as medidas obtidas pela estação meteorológica do Curso Técnico em Defesa Civil do IFC-Camboriú⁶ ,
que trata-se de um modelo comercial. A partir desta comparação, embora tenha havido grandes avanços, identificou-se uma inconsistência nos cálculos do pluviômetro, sensor esse que já está passando por melhorias.
A principal mudança foi a alteração de componentes estruturais da estação. Assim, foi desenvolvido um novo chassis principal, mais compacto e que permite a fixação em uma haste. Além disso, os sensores que medem a velocidade e direção do vento foram redesenhados com o objetivo de aumentar a sensibilidade, facilitar a produção e impedir a entrada de água nesses sensores. Também foram feitos os desenhos técnicos e a modelagem 3D dos componentes, bem como a fabricação dos componentes usando impressoras 3D, a montagem e os testes dos componentes.
Para aumentar a autonomia da estação implementou-se um sistema de geração de energia solar e baterias recarregáveis. Além disso, foi incorporado o monitoramento do nível de carga da bateria, cujos dados são transmitidos ao dashboard, permitindo o acompanhamento em tempo real do nível de carga do equipamento.
A próxima seção descreve em mais detalhes os componentes da estação, além de apresentar alguns dos artefatos gerados no processo de desenvolvimento do protótipo, apresentando os componentes e os dados acumulados durante o período.

### 3. RESULTADOS E DISCUSSÃO

O protótipo apresentado nesta fase do projeto é resultado da evolução direta da Fase 2 (PEREIRA et al., 2024). Enquanto a versão anterior tinha como principal objetivo a demonstração dos componentes com montagem provisória, o novo modelo foi projetado para ser uma solução mais robusta e autônoma. Seu núcleo, impresso em 3D, foi desenvolvido para acomodar a placa principal, baterias, pluviômetro e suporte dos sensores, além de proteger os componentes internos contra intempéries como ventos, chuvas e variações de temperatura. Ao longo do desenvolvimento foram aplicadas melhorias no design mecânico, nos sensores e no código fonte⁷
, garantindo facilidade de manutenção, maior precisão e redução no consumo de energia.
Inserida no conceito de Internet das Coisas (IoT), a estação integra sensores e conectividade em um único dispositivo, possibilitando a coleta e envio de dados ambientais. Essa abordagem busca permitir que o sistema funcione de maneira distribuída e autônoma, comunicando-se com a plataforma Thingsboard que fornece um painel apresentando os dados obtidos.

7 Código fonte: https://github.com/RafaelLuizC/estacao-ifc

6 Painel da Estação Meteorológica do TDC: https://ambientweather.net/dashboard/60a4f7e92df2960cb08d2a92a3607a94

Figura 1 - Painel de visualização dos dados Thingsboard.

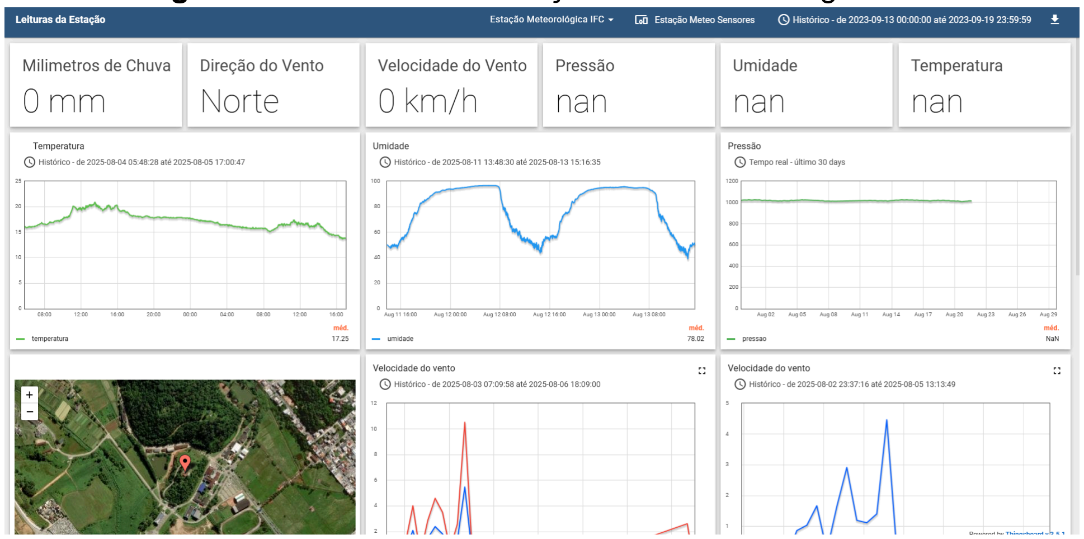
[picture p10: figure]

Fonte: Elaborado pelos autores
Para garantir a autonomia energética foi incorporado um sistema de geração de energia solar, o que permite que a estação funcione em locais externos sem energia elétrica, necessitando apenas de uma rede Wi-Fi para transmissão de dados. Contudo, os testes têm demonstrado a necessidade de melhorias, como a redução no consumo de energia da estação e a implementação de outro protocolo de comunicação, como a tecnologia LoRa, que permite a comunicação entre dispositivos a longas distâncias.

Figura 2 - Estação Meteorológica: Protótipo da Fase 1 do projeto.

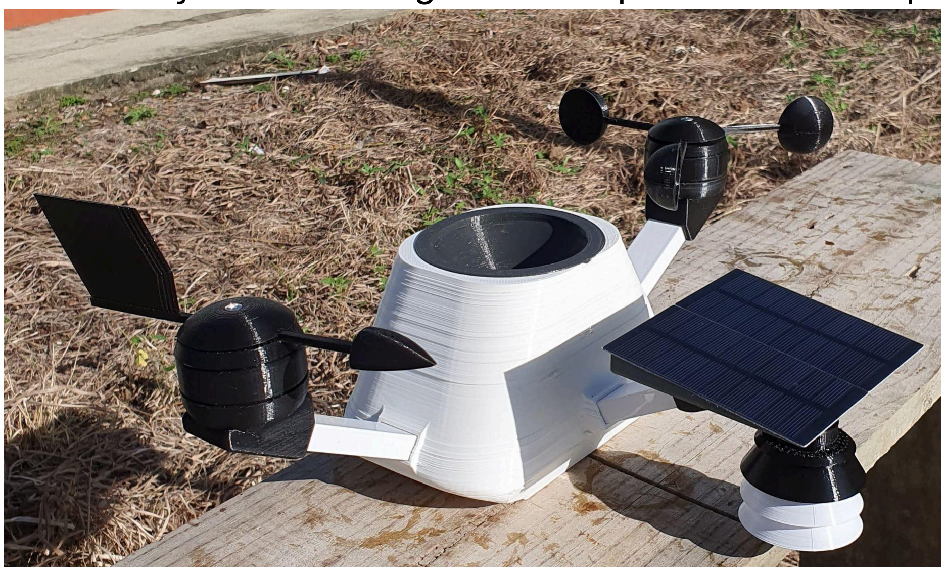
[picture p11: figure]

Fonte: Elaborado pelos autores.

O “cérebro” da estação é um microcontrolador modelo ESP32, um componente que tem como características a conectividade, o baixo consumo energético e a capacidade de processamento. O Wi-Fi integrado é utilizado tanto para o envio de dados ao servidor, quanto para a configuração da estação via modo Access-Point (AP), onde o usuário conecta-se à rede criada pela estação e por meio de uma página web é possível configurar aspectos como a rede.
Nessa versão foi implementado um sistema de sono inteligente: quando não há chuva ela opera em modo de economia de energia, despertando apenas em intervalos definidos para envio de dados. Ao detectar chuva entra em modo “alerta”, o que permite a contagem precisa dos pulsos gerados pelo pluviômetro. Abaixo é apresentada a nova placa projetada para integrar o ESP32, incluindo o circuito de carga e os conectores dos sensores. Além disso, a placa possui um botão responsável por calibrar a direção do vento e um mosfet AO3400 responsável pela métrica de carga da bateria.

Figura 3 - Estação Meteorológica: Placa da Estação

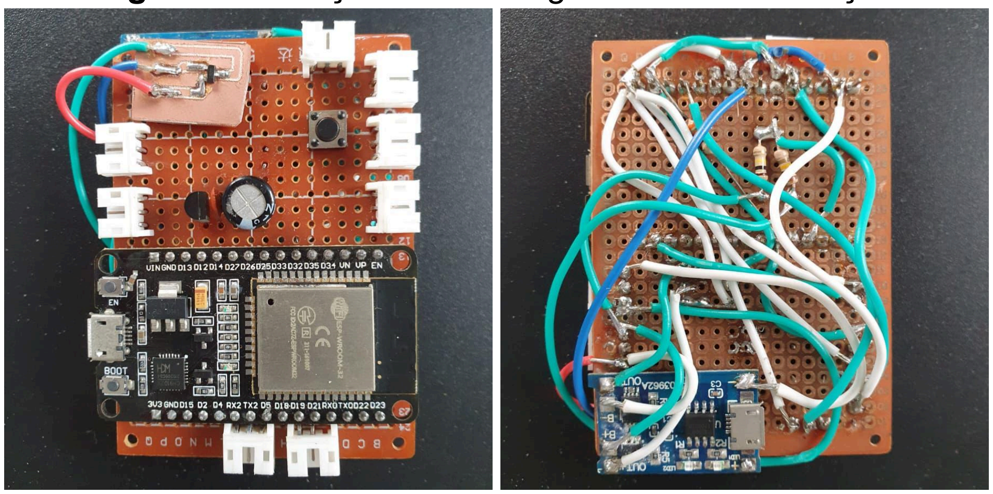
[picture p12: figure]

Fonte: Elaborado pelos autores

A estação transmite as seguintes métricas: pressão atmosférica, temperatura, umidade, precipitação, velocidade do vento e direção do vento. Entre as melhorias em relação à versão anterior destaca-se a substituição do sistema de reed switches para medição da direção do vento pelo sensor magnético AS5600, que fornece dados mais precisos e estáveis. O sensor de temperatura e umidade também foi atualizado, passando do DHT11 para o BME280, que oferece maior precisão e inclui a medição da pressão atmosférica, métrica sugerida pela Defesa Civil pois pode ajudar a prever fenômenos meteorológicos como microexplosões atmosféricas.
A parte física dos sensores de direção e velocidade do vento também foi redesenhada. O novo projeto 3D impede a entrada de líquidos no hardware, mesmo em períodos chuvosos intensos, garantindo a confiabilidade das medições. A seguir, serão apresentados dois registros do processo de modelagem 3D, demonstrando a evolução do protótipo.

Figura 4 - Estação Meteorológica: Protótipo da Fase 1 do projeto

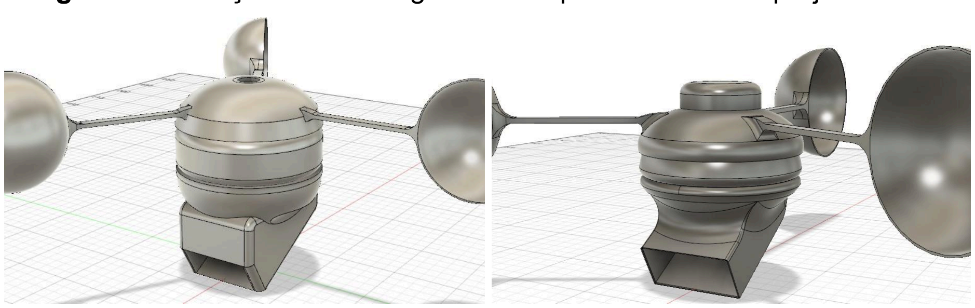
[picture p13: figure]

Fonte: Elaborado pelos autores

A primeira imagem mostra a segunda versão do sensor de velocidade do vento, enquanto a segunda imagem apresenta o modelo redesenhado. A nova versão conta com a parte superior rosqueável e foi pensada para oferecer maior proteção contra a entrada de água durante chuvas intensas. Além disso, o tamanho e o número de partes do sensor foram reduzidos: enquanto a segunda versão tem 8 partes, o novo desenho contém apenas 5, o que diminui o peso e o tempo de impressão. Esse redesenho aproxima mais o protótipo do objetivo do projeto: desenvolver uma estação com baixo custo e replicável.

### 4. CONSIDERAÇÕES FINAIS

A vigilância meteorológica desempenha papel essencial fornecendo dados que apoiam a tomada de decisão. Nesse contexto, soluções acessíveis de monitoramento climático tornam-se necessárias. Este trabalho apresentou a terceira fase do desenvolvimento de uma estação meteorológica de baixo custo. A proposta busca unir acessibilidade e confiabilidade, explorando a tecnologia IoT, utilizando componentes de baixo custo e impressão 3D.
O projeto conta com um protótipo funcional e em constante melhoria. Entre os principais avanços recentes destaca-se o início da produção de placas PCB personalizadas que substituem as conexões prototipadas e aumentam a confiabilidade do sistema eletrônico. Também foram realizados aprimoramentos no design estrutural e na calibração dos sensores.

Figura 5 - Placa PCB desenvolvida para o Chip LoRa SX1278

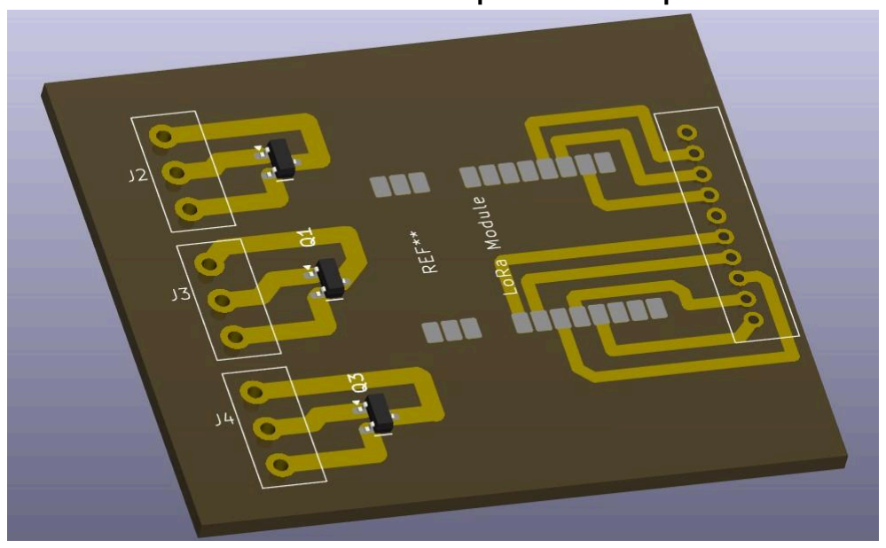
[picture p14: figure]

Fonte: Elaborado pelos autores

As próximas etapas previstas para o projeto compreendem a implementação de um sistema de transmissão de dados baseado em LoRa, tecnologia que amplia significativamente o alcance da comunicação sem fio e reduz o consumo energético. Além disso, ajustes futuros incluem o refinamento do pluviômetro, melhorias no anemômetro e a otimização do design 3D, visando reduzir o tempo de impressão e o custo do filamento, sem comprometer a resistência estrutural.
Este trabalho está inserido no contexto do projeto “Plataforma georreferenciada VigiAA - Vigilância do Aedes Aegypti”, o qual possui apoio do Edital FAPESC 37/2024.

### 5. REFERÊNCIAS

BRASIL. Ministério da Integração e do Desenvolvimento Regional. Secretaria de Proteção e Defesa Civil. Universidade Federal de Santa Catarina. Centro de Estudos e Pesquisas em Engenharia e Defesa Civil. Atlas Digital de Desastres no Brasil. Brasília: MIDR, 2025.

CONSELHO PERMANENTE DE AGROMETEOROLOGIA DO ESTADO DO RIO GRANDE DO SUL – COPAAERGS. Boletim de Informações nº 69, maio, 2024. Boletim Extraordinário: Catástrofe climática no Rio Grande do Sul – maio de 2024. Porto Alegre, RS, 23 maio 2024. 12 p. Documento técnico.

FREITAS, Emerson Carlos de; COELHO, André Luiz de Freitas. Desenvolvimento de estação meteorológica de baixo custo. 2025.

SANTOS, Bruno P. et al. Internet das coisas: da teoria à prática. Minicursos SBRC-Simpósio Brasileiro de Redes de Computadores e Sistemas Distribuıdos, v. 31, p. 16, 2016.

AIT MOUHA, Radouan Ait Radouan et al. Internet of things (IoT). Journal of Data Analysis and Information Processing, v. 9, n. 02, p. 77, 2021.

GONÇALVES, Caio Philipe Nascimento et al. Estação meteorológica de baixo custo para monitoramento do microclima na lavoura de cacau. In: Escola Regional de Computação Bahia, Alagoas e Sergipe (ERBASE). SBC, 2024. p. 74-83.

PEREIRA, Rafael Luiz et al. DESENVOLVIMENTO DE UMA ESTAÇÃO METEOROLÓGICA DE BAIXO CUSTO-FASE II. Anais da Feira de Iniciação Científica e Extensão (FICE) Campus Camboriú, 2024.

BOCCATO, Vera Regina Casari. Metodologia da pesquisa bibliográfica na área odontológica e o artigo científico como forma de comunicação. Rev. Odontol. Univ. Cidade São Paulo, São Paulo, v. 18, n. 3, p. 265-274, 2006.

FREITAS JUNIOR, Vanderlei. et al. A pesquisa científica e tecnológica. Revista Espacios, v. 35, n. 9, 2014. Disponível em: https://www.revistaespacios.com/a14v35n09/14350913.html. Acesso em: 25 ago. 2023.

CUPANI, Alberto. La peculiaridad del conocimiento tecnológico. Scientiae Studia, São Paulo, v. 4, n. 3, p. 353-371, 2006. Disponível em: http://www.scielo.br/pdf/ss/v4n3/a01v4n3.pdf. Acesso em: 6 abr. 2012.

THINGSBOARD. ThingsBoard - Open Source IoT Platform. [S. l.], c2024. Página inicial. Disponível em: https://thingsboard.io. Acesso em: 27 ago. 2024.

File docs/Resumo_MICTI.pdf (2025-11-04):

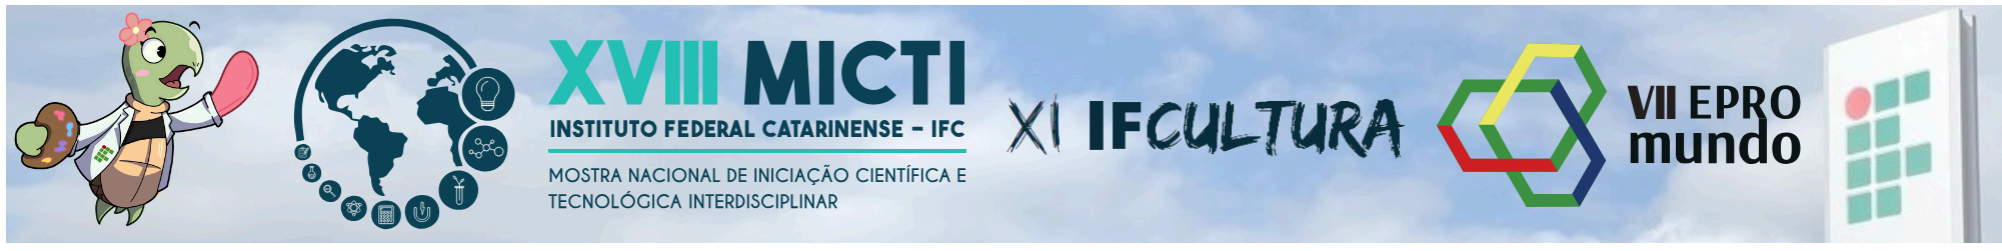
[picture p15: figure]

ESTAÇÃO METEOROLÓGICA DE BAIXO CUSTO: RESULTADOS E DESAFIOS Rafael Luiz C. Santos Pereira¹

; Cauã da Costa Silva²

; Rafael de Moura Speroni³ ;
Angelo Augusto Frozza⁴

; Joice Seleme Mota⁵

Este trabalho apresenta a terceira fase do desenvolvimento de uma estação meteorológica de baixo custo baseada no conceito de Internet das Coisas (IoT). A pesquisa, classificada como tecnológica, seguiu um ciclo de desenvolvimento iterativo, que incluiu o redesenho de componentes, a fabricação via impressão 3D, a montagem do protótipo e testes de campo do desenho proposto. A validação dos dados foi realizada por comparação com uma estação comercial, o que permitiu identificar inconsistências e direcionar melhorias. A justificativa baseia-se na necessidade de soluções acessíveis para o monitoramento climático, em resposta a desastres como os eventos hidrológicos extremos que afetaram o sul do Brasil no ano de 2024. Além disso, no âmbito do Projeto VigiAA, há o potencial para a coleta de dados climáticos em pontos de interesse, com o objetivo de relacioná-los com outros dados obtidos pela plataforma, relativos ao combate ao Aedes Aegypti. Os resultados do protótipo indicam que a estação de baixo custo, baseada em IoT, possibilita a coleta e transmissão de dados ambientais em tempo real, oferecendo uma ferramenta para a criação de uma rede de monitoramento climático inteligente e integrada. Entre as tecnologias e componentes implementados destacam-se: o microcontrolador ESP32 como núcleo de processamento, houve uma significativa atualização nos sensores, como o BME280 para pressão atmosférica, temperatura e umidade; e o hardware do anemógrafo evoluiu de reed switches para um sensor magnético AS5600, que garante dados mais estáveis. O redesenho 3D do anemômetro, e anemógrafo não só aprimorou a precisão, mas também impediu a infiltração de água e simplificou a produção, reduzindo o número de peças. Por fim, a autonomia foi reforçada por um sistema de energia solar e com um software otimizado para maximizar a autonomia energética, que agora inclui o monitoramento do nível da bateria e carga, permitindo uma gestão mais eficaz do equipamento em campo. Além disso, a integração com a plataforma IoT Thingsboard permite a visualização e o armazenamento dos dados coletados. Conclui-se que o protótipo mostra viável e que os dados gerados são consistentes com aqueles oriundos de uma estação meteorológica comercial. Os principais desafios identificados para as próximas etapas

5 Professor colaborador, IFC Camboriú, joice.mota@ifc.edu.br

4 Professor colaborador, IFC Camboriú, | angelo.frozza@ifc.edu.br
3 Professor orientador, IFC Camboriú, | rafael.speroni@ifc.edu.br

2 Estudante do curso Bacharelado em Sistemas de informação, IFC Camboriú, caua.silva.ifc@gmail.com

1 Estudante do curso Bacharelado em Sistemas de informação, IFC Camboriú, rafaelluizcc@gmail.com

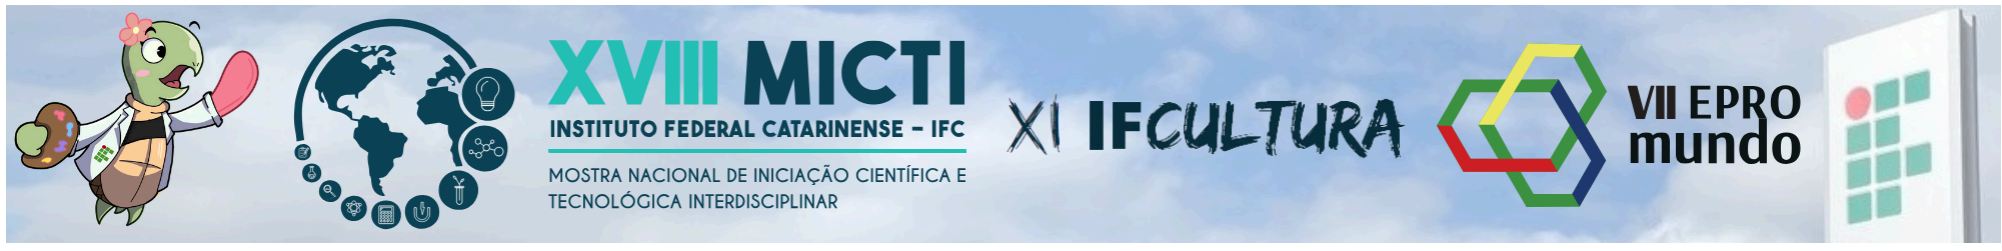
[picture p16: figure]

envolvem a necessidade de aprimorar a precisão de sensores como o pluviômetro, otimizar o consumo de energia e ampliar o alcance da comunicação, que atualmente depende de redes Wi-Fi. Assim, o trabalho apresenta um protótipo funcional em constante evolução, e fornece informações para o desenvolvimento e a replicação de estações meteorológicas acessíveis.

Palavras-chave: Palavras-chave: estação meteorológica; (IoT); clima;

O projeto de pesquisa “Plataforma georreferenciada VigiAA – Vigilância do Aedes Aegypti”, foi aprovado e financiado pela FAPESC no Edital 37/2024.

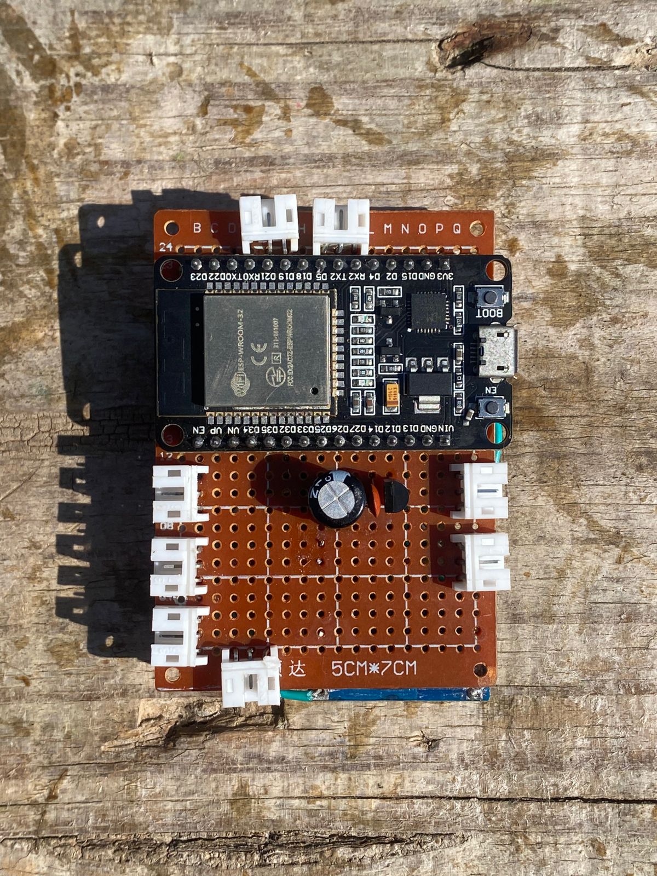
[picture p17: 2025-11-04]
images/pcb_esp32_2.jpg

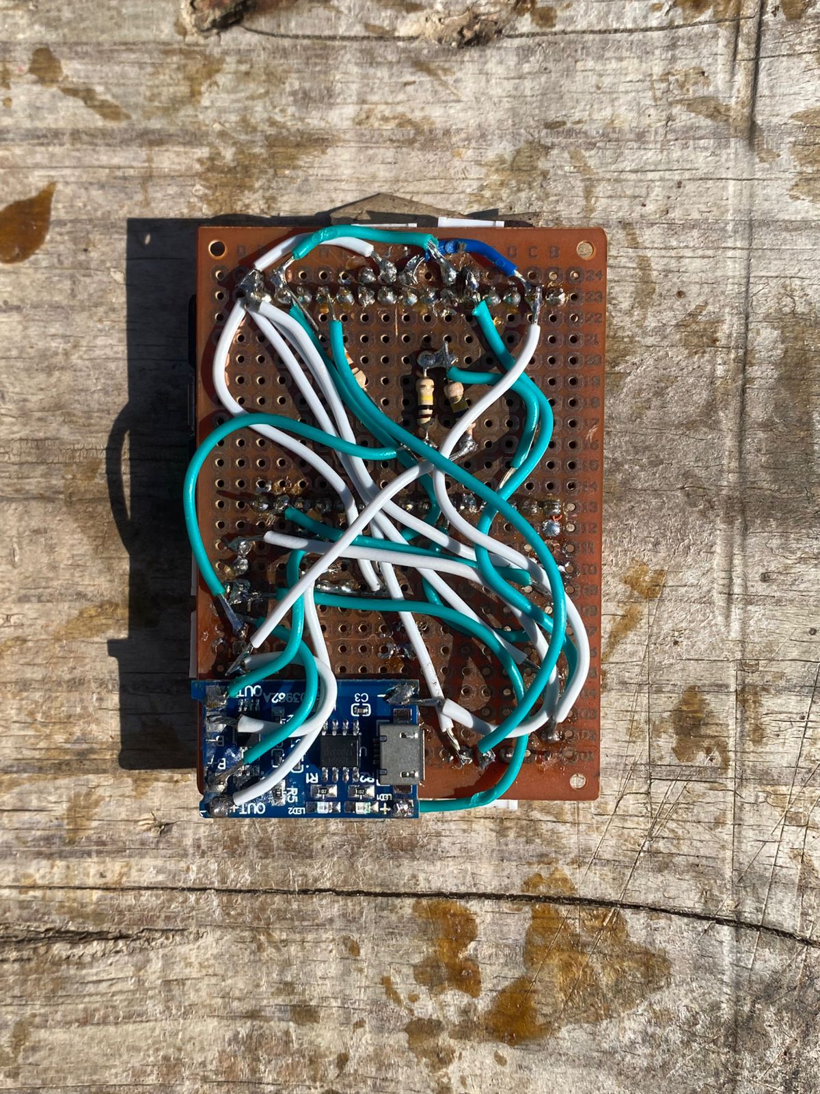
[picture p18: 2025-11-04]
images/traseira_pcb_esp32.jpg

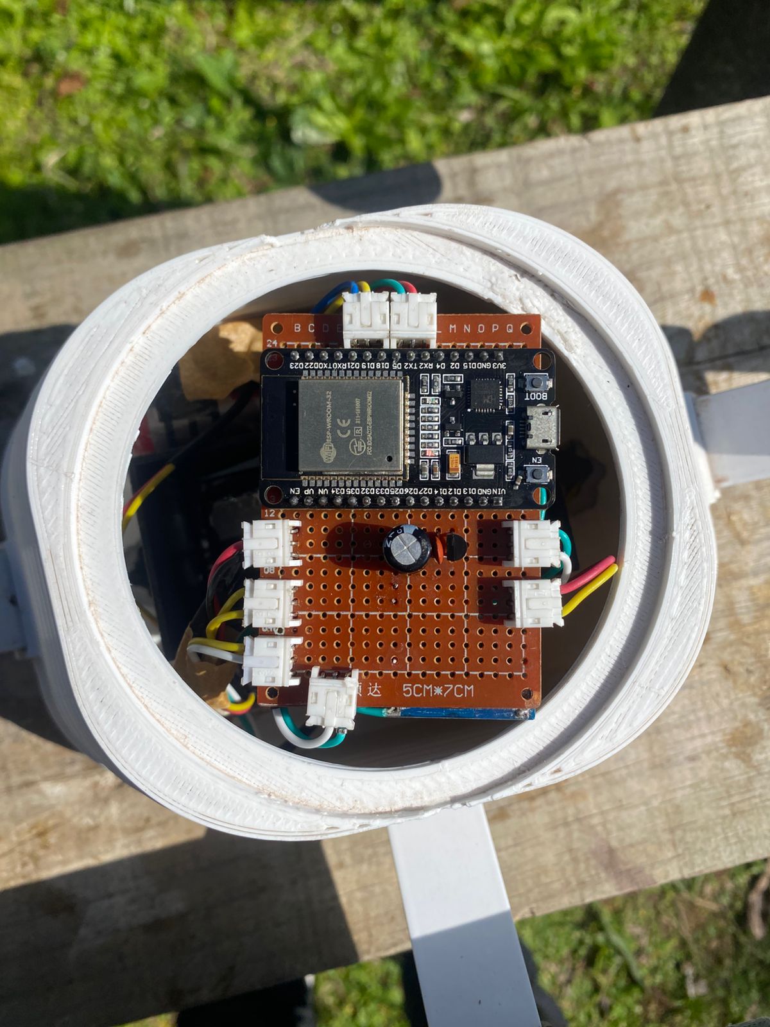
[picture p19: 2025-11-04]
images/pcb_conectada.jpg

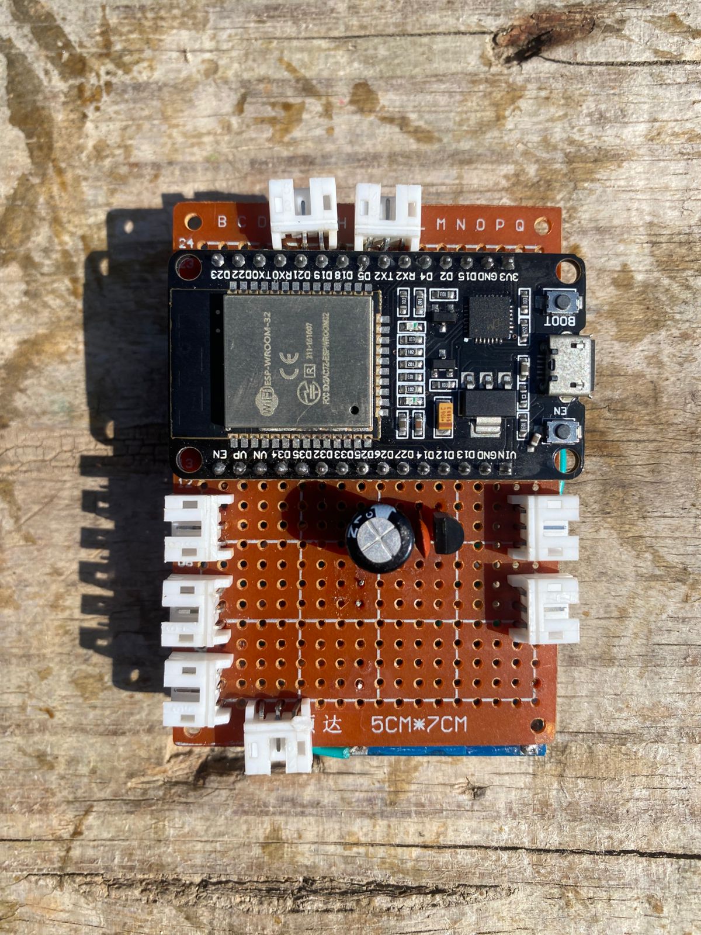
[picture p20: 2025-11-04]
images/pcb_esp32.jpg

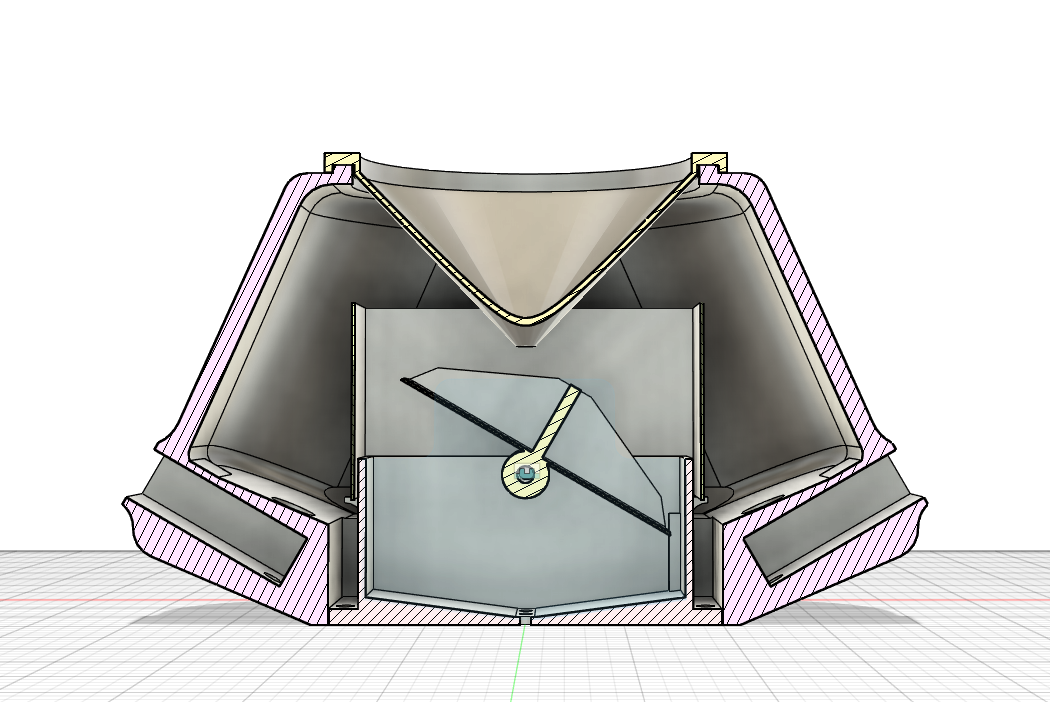
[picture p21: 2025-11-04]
images/visao_lateral_carcaca.png

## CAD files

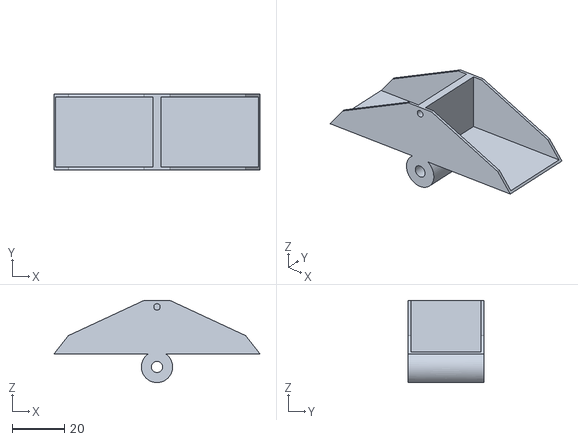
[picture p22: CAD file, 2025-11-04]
hardware/3D_MODELS/PluviometroBascula.stl
79.0 x 29.0 x 31.5

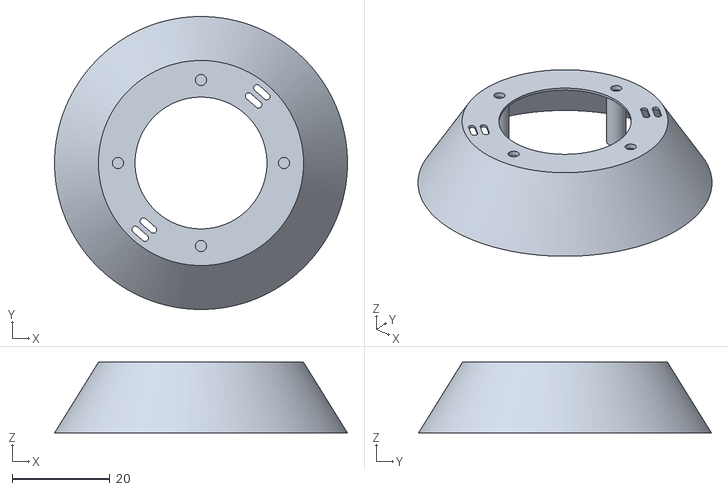
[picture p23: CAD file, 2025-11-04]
hardware/3D_MODELS/SteversonMeio.stl
60.0 x 60.0 x 14.5

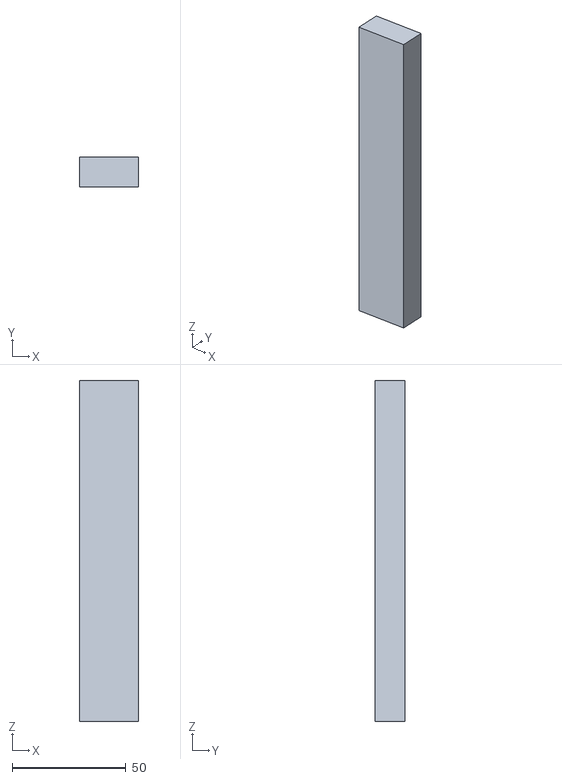
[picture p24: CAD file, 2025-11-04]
hardware/3D_MODELS/PluviometroSuporteBascula.stl
26.0 x 13.0 x 150.0

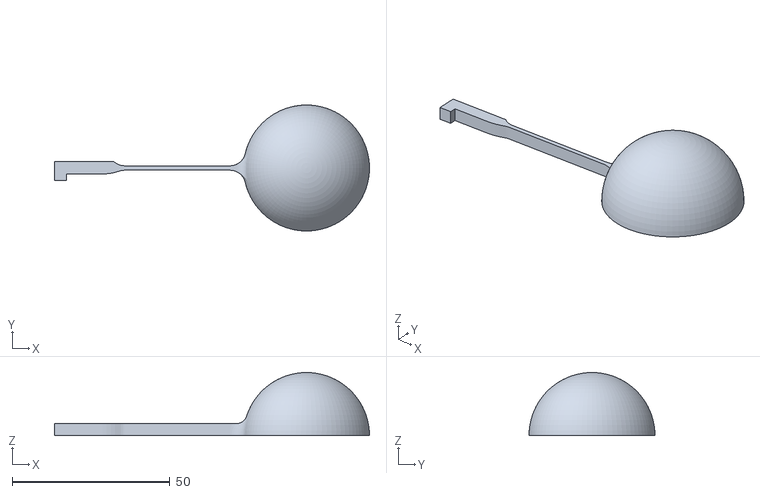
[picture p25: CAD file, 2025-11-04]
hardware/3D_MODELS/VelVentoPa.stl
100.0 x 40.0 x 20.0

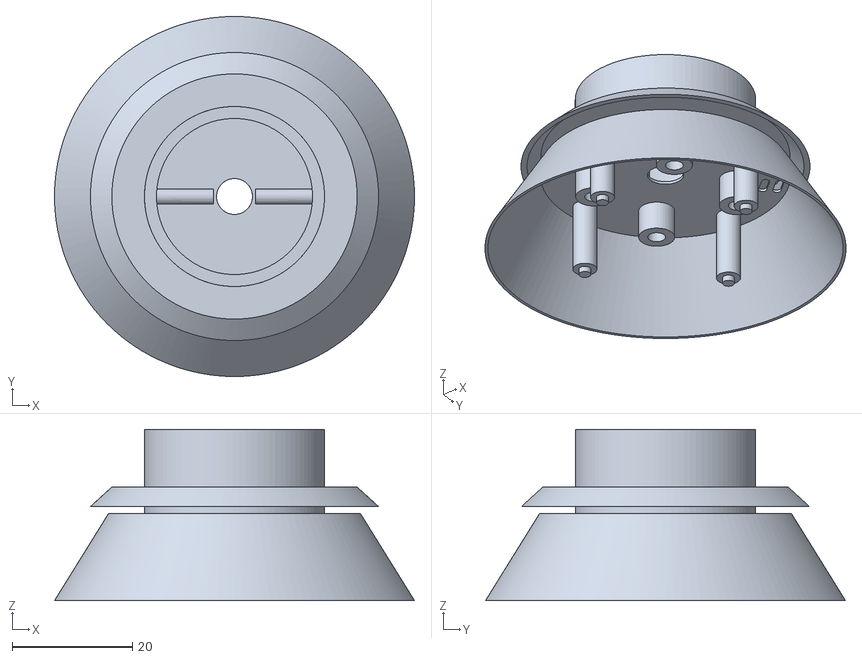
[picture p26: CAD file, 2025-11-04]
hardware/3D_MODELS/SteversonTopo.stl
60.0 x 60.0 x 28.5

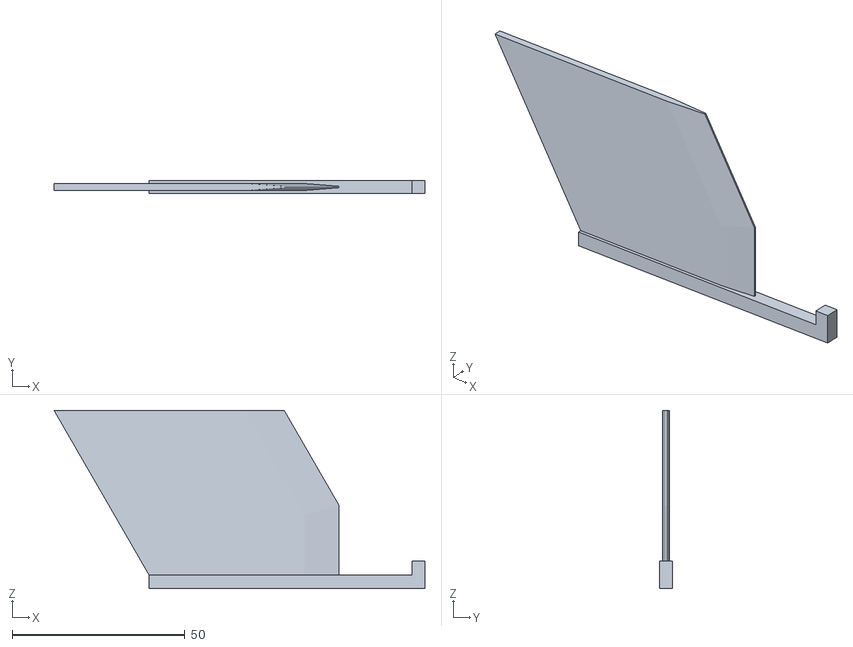
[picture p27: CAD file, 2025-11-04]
hardware/3D_MODELS/PontaTrasDirVento.stl
107.2 x 3.80 x 51.5

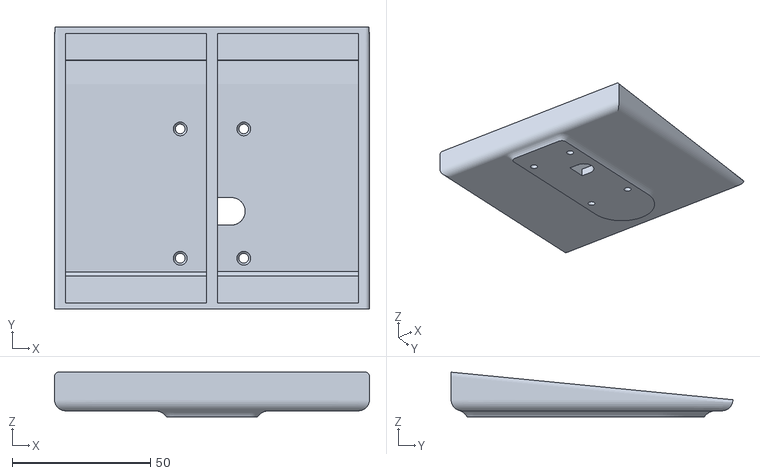
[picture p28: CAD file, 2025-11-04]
hardware/3D_MODELS/SuportePainelSolar.stl
114.0 x 102.0 x 16.2

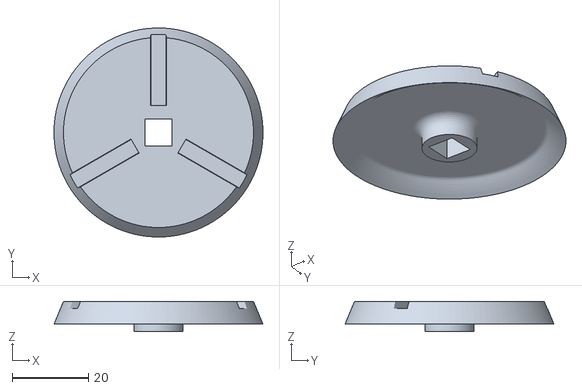
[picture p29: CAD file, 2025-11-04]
hardware/3D_MODELS/VelVentoBaixa.stl
55.0 x 55.0 x 8.00

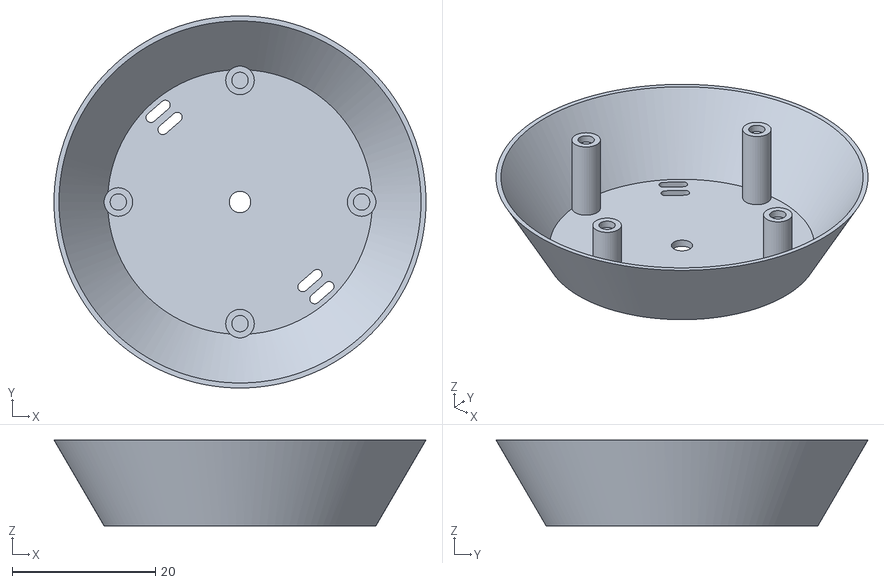
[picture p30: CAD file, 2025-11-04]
hardware/3D_MODELS/SteversonFundo.stl
52.0 x 52.0 x 12.0

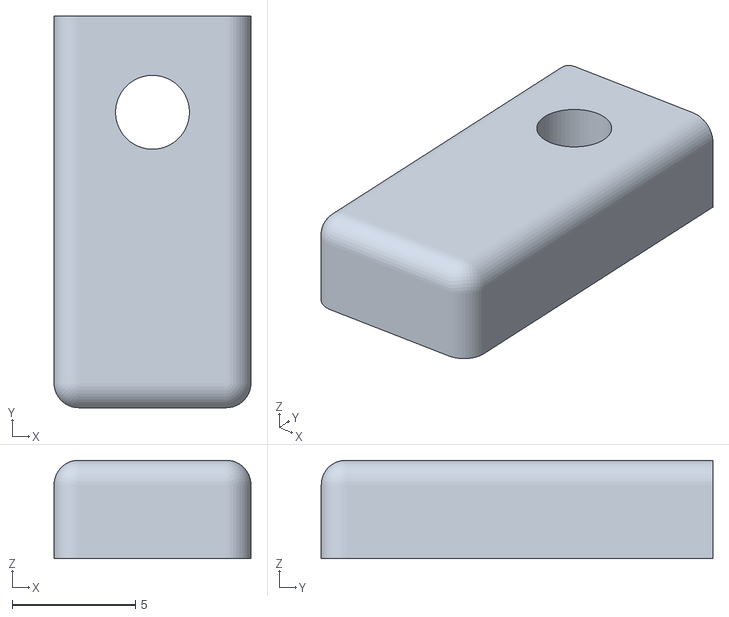
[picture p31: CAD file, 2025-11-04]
hardware/3D_MODELS/PluviometroTrava.stl
8.00 x 15.9 x 4.00

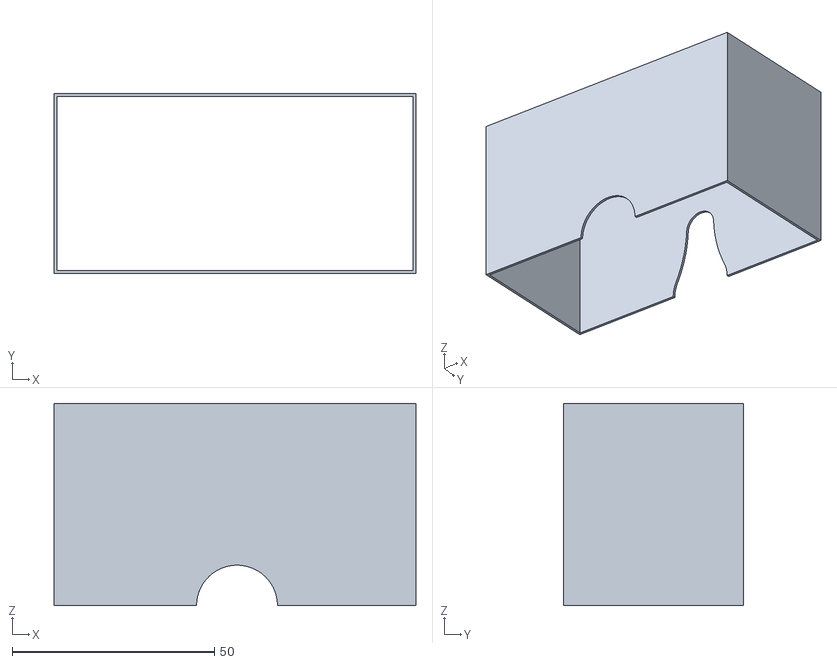
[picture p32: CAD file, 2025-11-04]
hardware/3D_MODELS/PluviometroCaixaRespingo.stl
89.5 x 44.5 x 50.0

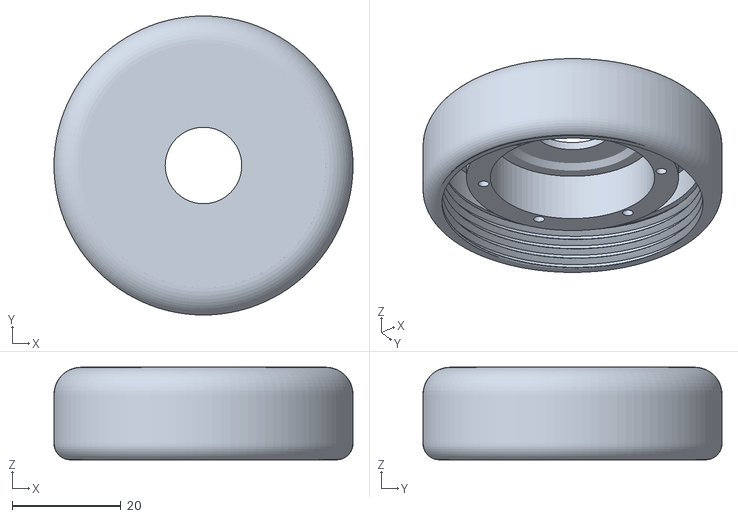
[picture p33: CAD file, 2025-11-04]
hardware/3D_MODELS/SuporteSensoresRolamento.stl
55.0 x 55.0 x 17.1

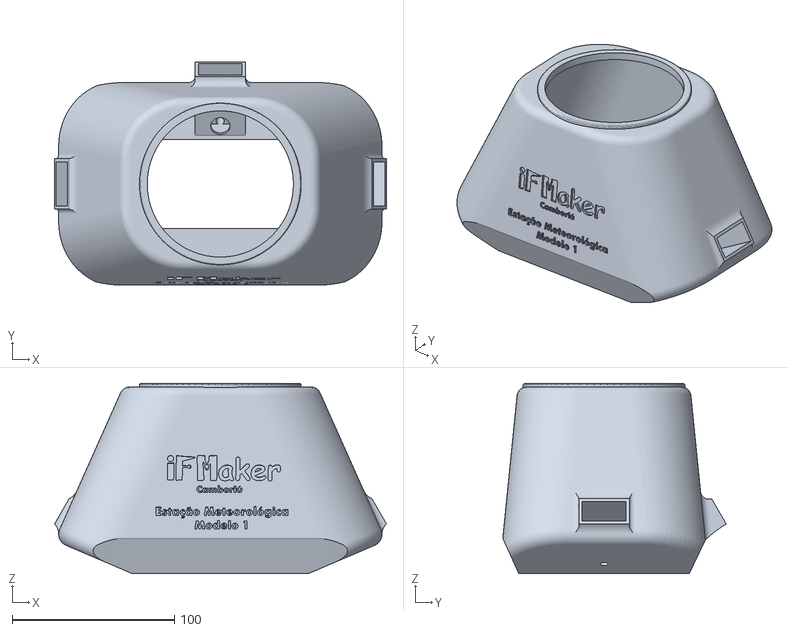
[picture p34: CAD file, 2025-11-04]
hardware/3D_MODELS/NucleoEstacao.stl
204.4 x 137.6 x 117.0

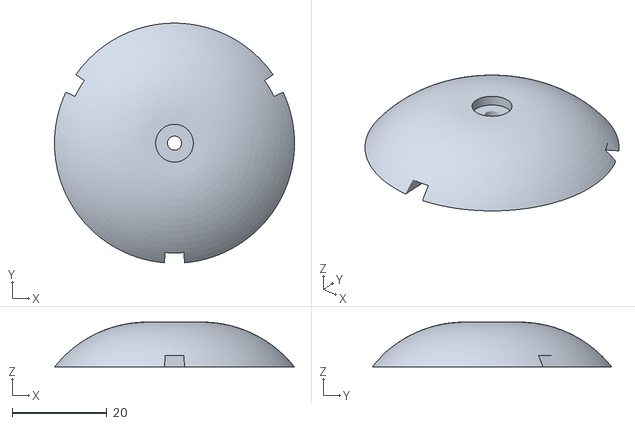
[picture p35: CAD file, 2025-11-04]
hardware/3D_MODELS/VelVentoTopo.stl
50.8 x 50.7 x 9.50

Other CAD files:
hardware/3D_MODELS/PeçaBaixaSuportePainelSolar.stl
hardware/3D_MODELS/PontaFrenteDirVento.stl
hardware/3D_MODELS/PluviometroCorpo.stl
hardware/3D_MODELS/SuporteSensoresBaixo.stl
hardware/3D_MODELS/EixoVelVento.stl
hardware/3D_MODELS/PluviometroFunil.stl

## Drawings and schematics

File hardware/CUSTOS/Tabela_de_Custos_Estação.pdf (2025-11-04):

### Materiais Eletronicos

Parte Estação | Item | Custo Unitario | Custo Total | Unidades | Link | Descrição
Anemômetro | Imã Neodinio Pequeno 2mm/ 3mm | R$ 0,14 | R$ 7,47 50un | | 1 Link Imãs (https://www.lojadoima.com.br/ima-neodimio-disco-3x2-n35/p?idsku=2279&gad_source=1) | Essa peça é fixada ao corpo das pás.
Anemômetro | Reed Switch 14mm 2mm diam | R$ 2,00 | R$20,00 10un | | 1 Link Reed Switch ML (https://produto.mercadolivre.com.br/MLB-1867569331-kit-10-reed-switch-na-214mm-sensor-magnetico-ampola-branca-_JM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) | Essa peça é fixada ao corpo do sensor, para captar a rotação.
Anemômetro | Conector Femea 3 pinos | 1 | Interface de conexão Sensor-Placa
Anemômetro | Fio Vermelho 3.3v - Sensor/Interface | | | 10 cm | | Fio Positivo
Anemômetro | Fio Amarelo Dados - Sensor/Inferface | | | 10 cm | | Fio de Dados
Anemômetro | Placa Pequena Interface | R$ 1,00 | R$ 1,00 | 1 | 1/4 de Placa Perfurada para conectar o conector femea
Chicote Eletrico Fio Amarelo Dados - Sensor/Inferface | 2m | Fio de Dados
Chicote Eletrico Fio Vermelho 3.3v - Sensor/Interface | 1m | Fio Positivo
Chicote Eletrico Fio Azul GND - Sensor/Inferface | 2m | Fio Azul GND
Chicote Eletrico Conector Macho 3 Vias | 11 | Conector Macho do Chicote Eletrico da Estação
Placa Principal Placa Perfurada 5x7cm | R$ 2,70 | R$ 2,70 | Link 10 Placas PerfuradasPlaca (https://produto.mercadolivre.com.br/MLB-811753644-10x-placa-de-fenolite-ilhada-5x7-cm-pcb-perfurada-prototipo-_JM) Principal, Interface onde vai o ESP32
Placa Principal Conector fêmea 3 pinos | 7 | Conectores dos Sensores
Placa Principal ESP32 DevKit1 | R$ 50,00 | R$ 50,00 | 1 Link ESP32 Devkit (https://produto.mercadolivre.com.br/MLB-2727332335-esp32-wroom-devkit-v1-com-nota-fiscal-eletrnica-nfe-_JM) | Placa ESP32
Placa Principal Resistor 330r | R$, 0,13 | R$ 1,30 | 10 Link 100 Resistores (https://produto.mercadolivre.com.br/MLB-3626031945-100-resistores-filme-de-carbono-14w-5-escolha-valor-_JM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) | Resistores para reduzir interferencias nos dados
Placa Principal Fios de Cobre | R$ 5,3 | R$15,90 | 40 cm | Cabo RJ45 1.5m (https://www.mercadolivre.com.br/cabo-de-rede-cat6-15m-azul-ultra-velocidade-15-metros-rj45/p/MLB28646473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) | Fios para ligação entre os sensores
Pluviometro | Reed Switch 14mm 2mm diam | R$ 2,00 | R$20,00 10un | | 1 Link Reed Switch ML (https://produto.mercadolivre.com.br/MLB-1867569331-kit-10-reed-switch-na-214mm-sensor-magnetico-ampola-branca-_JM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) | Essa peça é fixada ao corpo do Pluviometro
Pluviometro | Imã Neodinio Pequeno 2mm/ 3mm | R$ 0,14 | R$ 7,47 50un | | 1 Link Imãs (https://www.lojadoima.com.br/ima-neodimio-disco-3x2-n35/p?idsku=2279&gad_source=1) | Essa peça é fixada ao corpo da balança do Pluviometro
Pluviometro | Eixo Metalico 6cm/0.5mm | R$ 5,00 | R$ 5,00 | | 1 Eixo AliExpress (https://pt.aliexpress.com/item/1005006737253242.html?scm_id=1007.40000.327270.0&scm-url=1007.40000.327270.0) | Eixo de rotação da balança
Pluviometro | Fio Vermelho 3.3v - Sensor/Interface | | | 10cm | | Fio Positivo
Pluviometro | Fio Amarelo Dados - Sensor/Inferface | | | 10cm | | Fio de Dados
Pluviometro | Placa Pequena Interface | R$ 1,00 | R$ 1,00 | 1 | 1/4 de Placa Perfurada para conectar o conector femea
Direção Vento | Imã Neodinio Pequeno 2mm/ 3mm | R$ 0,14 | R$ 7,47 50un | | 1 Link Imãs (https://www.lojadoima.com.br/ima-neodimio-disco-3x2-n35/p?idsku=2279&gad_source=1) | Essa peça é fixada ao corpo do sensor, para captar a rotação.
Direção Vento | Sensor De Ângulo Magnético As5600 | R$ 16,00 | R$ 16,00 | 1 https://www.mercadolivre.com.br/sensor-de-ngulo-magnetico-as5600-potenciometro-arduino/p/MLB37498209 Essa peça é fixada ao corpo do sensor, para captar a direção, cada reed switch para uma direção.
Direção Vento | Rolamento 6200 2rs | R$ 4,00 | R$ 40,00 10un | 1 https://produto.mercadolivre.com.br/MLB-1353482659-rolamento-6200-2rs-kit-com-10-pcs-10x30x9-_JM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 Rolamento Superior e Inferior ao Eixo.
Direção Vento | Conector Femea 3 vias | 1 | Interface de conexão Sensor-Placa
Direção Vento | Fio Vermelho 3.3v - Sensor/Interface | | | 30cm | | Fio Positivo
Direção Vento | Fio Amarelo Dados - Sensor/Inferface | | | 30cm | | Fio de Dados
Direção Vento | Placa Pequena Interface | R$ 1,00 | R$ 1,00 | 1 | 1/4 de Placa Perfurada para conectar o conector femea
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

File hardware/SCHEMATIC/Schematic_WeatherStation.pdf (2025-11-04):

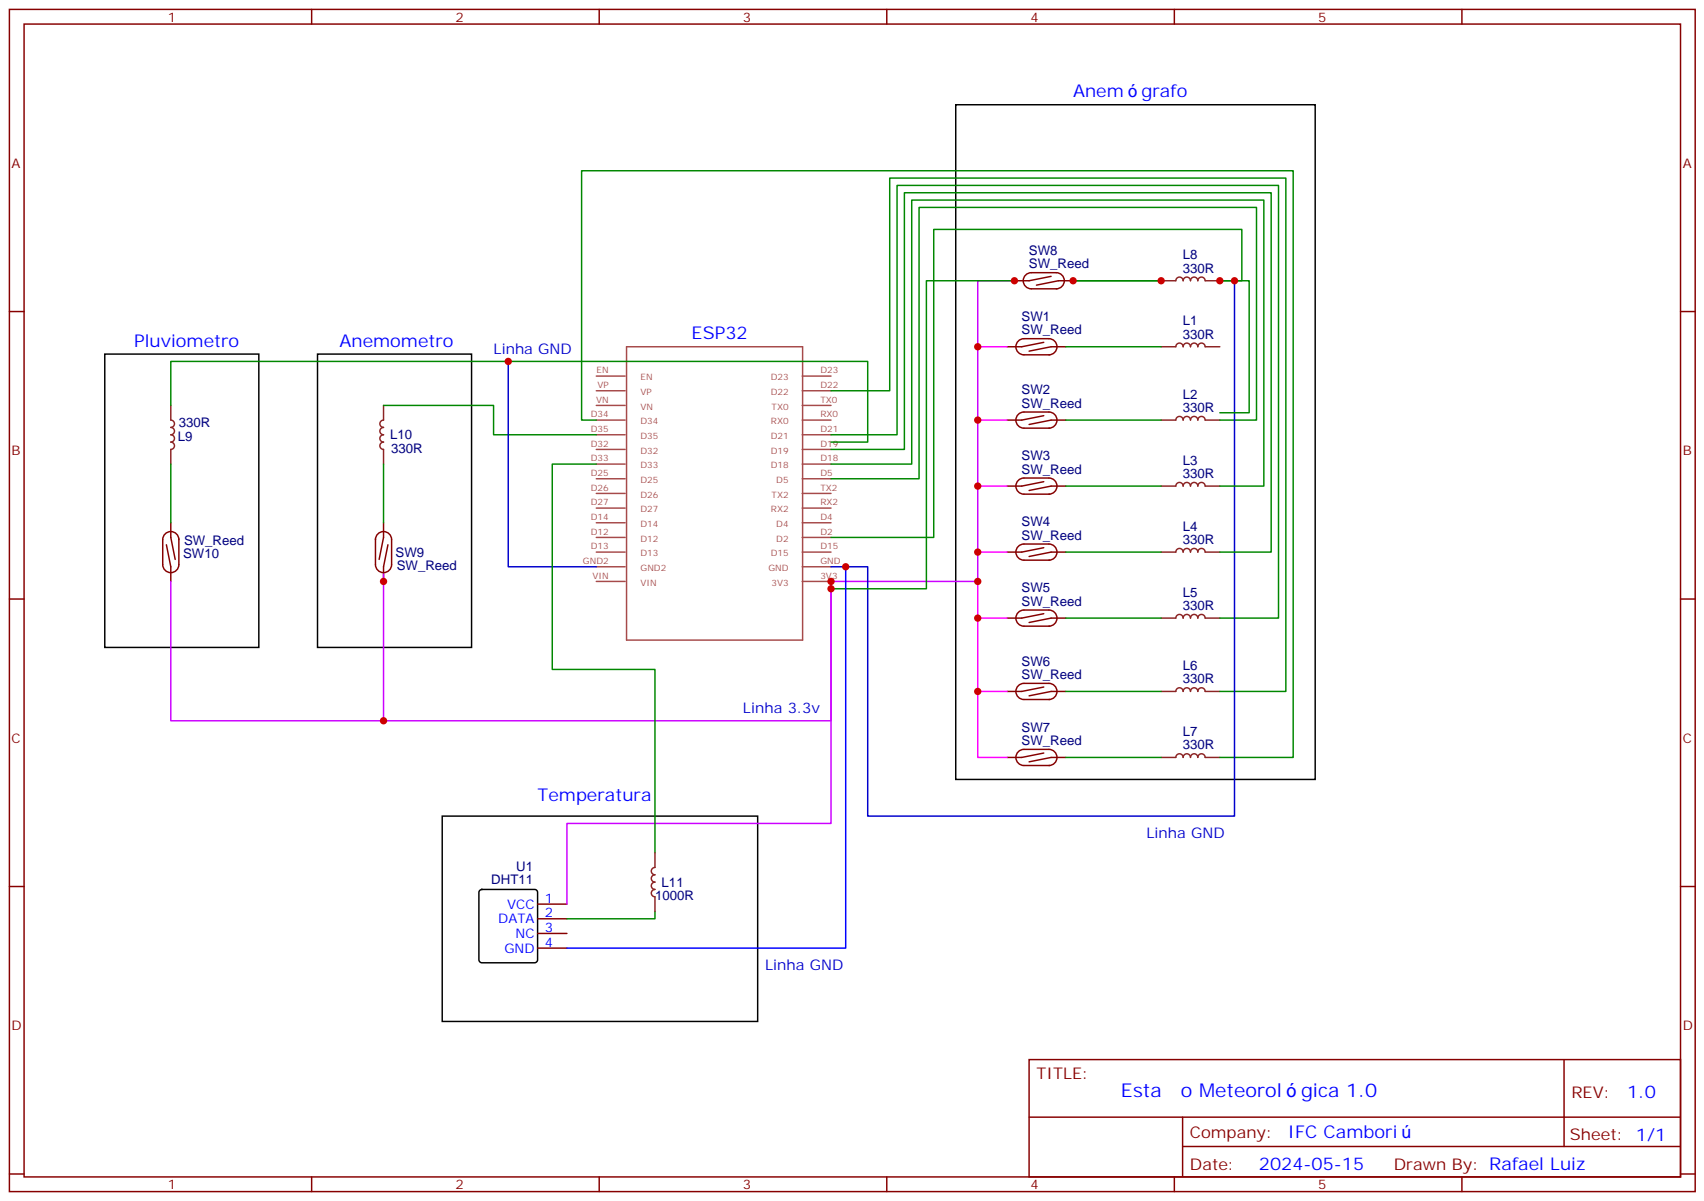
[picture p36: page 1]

Drawn By: Rafael Luiz

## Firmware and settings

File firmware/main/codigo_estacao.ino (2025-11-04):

#include <DHT.h>
#include <HTTP_Method.h>
#include <Uri.h>
#include <WiFi.h>
#include <DHT_U.h>
#include <Adafruit_Sensor.h>
#include <HTTPClient.h>
#include <ThingsBoard.h>
#include <esp_wifi.h>
#include <WebServer.h>
#include <Preferences.h>

const char* ssid = "VISITANTES";
const char* password = "";

//Inicia o Objeto preferences.
Preferences preferences; 
WebServer server(80);

//Aqui estão as informações de conexão do ESP
const char *apSSID = "ESP32_Config"; //Nome da Rede do ESP.
const char *apPassword = "12345678"; //Senha da Rede do ESP.

//Variavel que determina o tempo entre as amostras da Estação.
int delaytime = 1*289*1000000;  //Invervalo entre as amostras
//Definido em 49 Segundos por conta do processo de coleta dos dados demorar 11 Segundos.


//Dados de Conexão com o Servidor.
const char* thingsboardServer = "https://tb.geati.camboriu.ifc.edu.br/";
const char* accessToken = "f5a3iEEZ2iPhdIoVewTk";
const char* deviceId = "f0b973e0-5642-11ee-bdd4-b1244f07481c";

//Aqui se define as entradas que receberão os Reed Switch.
// O Valor numerico se refere ao numero da porta, e o "PIN" é para armazenar a variavel que esta recebendo o sinal.
const int PIN1 = 2;  // Reed Switch Pin
const int PIN2 = 4;  // Reed Switch Pin
const int PIN3 = 5;  // Reed Switch Pin
const int PIN4 = 18;  // Reed Switch Pin
const int PIN5 = 19;  // Reed Switch Pin
const int PIN6 = 21;  // Reed Switch Pin
const int PIN7 = 22;  // Reed Switch Pin
const int PIN8 = 34;  // Reed Switch Pin

const int PLUVIPIN = 23;  // Reed Switch Pin

const int ANEMPIN = 32;  // Reed Switch Pin

//Pin do DHT11
#define DHTPIN 25
#define DHTTYPE DHT11

DHT dht(DHTPIN, DHTTYPE);
float h;
float t;
float hic = dht.computeHeatIndex(t, h, false);


//Variaveis dos Sensores
String direcao = "erro"; // Variável para armazenar a direção

//Variaveis do Sensor Pluviometro.
volatile int ciclo = 0;
volatile float mm = 0;
volatile unsigned long lastPluviTime = 0;
const unsigned long debouncePluviDelay = 100; //Segundo o Paulo, essa Variavel serve para desativar o Pluviometor por 100 milisegundos para evitar que quando a bascula caia, não tenha um efeito rebote que reacione o sensor.


//Variaveis do Sensor de Velocidade do Vento.
const float pi = 3.14159265;     //Número de pi
int period = 5000;               //Tempo de medida(miliseconds)
int radius = 65;                //Raio do anemometro(mm)
unsigned int counter = 0;        //Contador para o sensor
unsigned int RPM = 0;            //Rotações por minuto
float speedwind = 0;             //Velocidade do vento (m/s)
float windspeed = 0;             //Velocidade do vento (km/h)

//Função que gera a pagina HTML de configuração da Rede.
void handleRoot() {
  String html = "<html><body>";
  html += "<h1>Configurar Rede WiFi</h1>";
  html += "<form action='/save' method='POST'>";
  html += "SSID: <input type='text' name='ssid'><br>";
  html += "Senha: <input type='text' name='password'><br>";
  html += "<input type='submit' value='Salvar'>";
  html += "</form>";
  html += "</body></html>";

  server.send(200, "text/html", html);
}

// Função para lidar com o salvamento das configurações
void handleSave() {
  String ssid = server.arg("ssid");
  String password = server.arg("password");

//  Caso não tenha nenhuma rede salva, ou a rede salva não possua nenhum caracter, será iniciado o servidor.
  if (ssid.length() > 0 ) {
    preferences.putString("ssid", ssid);
    preferences.putString("password", password);

    String response = "<html><body>";
    response += "<h1>Configurações Salvas</h1>";
    response += "<p>O dispositivo irá reiniciar e tentar conectar-se à rede configurada.</p>";
    response += "</body></html>";

    server.send(200, "text/html", response);
    delay(2000);
    ESP.restart();
  } else {
    server.send(400, "text/html", "<h1>Falha ao salvar as configurações. Por favor, tente novamente.</h1>");
  }
}

void setup() {
  Serial.begin(9600);   // Init serial 9600
  // Iniciar o NVS
  preferences.begin("wifi-config", false);

  esp_sleep_enable_timer_wakeup(delaytime);
  setCpuFrequencyMhz(80);

  // Verificar se há configurações salvas
  String ssid = preferences.getString("ssid", "");
  String password = preferences.getString("password", "");

  //  Caso o nome da rede salva seja maior que 0, Ele tenta se conectar a rede.
  if (ssid.length() > 0 ) {
    // Tentar conectar à rede configurada
    WiFi.begin(ssid.c_str(), password.c_str());

    Serial.print("Conectando a ");
    Serial.println(ssid);

    int retryCount = 0;
    while (WiFi.status() != WL_CONNECTED && retryCount < 20) {
      delay(500);
      Serial.print(".");
      retryCount++;
    }

    if (WiFi.status() == WL_CONNECTED) {
      Serial.println("Conectado!");
      Serial.print("IP: ");
      Serial.println(WiFi.localIP());
      return;
    } else {
      Serial.println("\nFalha ao conectar. Iniciando modo AP.");
    }
  }

  // Modo AP
  WiFi.softAP(apSSID, apPassword);
  Serial.print("AP IP: ");
  Serial.println(WiFi.softAPIP());

  // Configurar as rotas do servidor web
  server.on("/", handleRoot);
  server.on("/save", HTTP_POST, handleSave);
  server.begin();
  Serial.println("Servidor web iniciado.");

  //Abaixo é o codigo original da Estação, e acima é o codigo do modo AP.

  pinMode(PIN1, INPUT);  // Set pin as INPUT
  pinMode(PIN2, INPUT);  // Set pin as INPUT
  pinMode(PIN3, INPUT);  // Set pin as INPUT
  pinMode(PIN4, INPUT);  // Set pin as INPUT
  pinMode(PIN5, INPUT);  // Set pin as INPUT
  pinMode(PIN6, INPUT);  // Set pin as INPUT
  pinMode(PIN7, INPUT);  // Set pin as INPUT
  pinMode(PIN8, INPUT);  // Set pin as INPUT
  
  pinMode(PLUVIPIN, INPUT);  // Set pin as INPUT
  pinMode(ANEMPIN, INPUT);  // Set pin as INPUT
  pinMode(DHTPIN, INPUT);  // Set pin as INPUT
  
  attachInterrupt(23, pluvi, CHANGE);  // Associa interrupção ao pino 2

  dht.begin();
}

void loop() {
  server.handleClient();

  // Tentar conectar à rede configurada
  WiFi.begin(ssid, password);

  Serial.print("Conectando a ");
  Serial.println(ssid);

  int retryCount = 0;
  while (WiFi.status() != WL_CONNECTED && retryCount < 20) {
    delay(500);
    Serial.print(".");
    retryCount++;
  }

  if (WiFi.status() == WL_CONNECTED) {
    Serial.println("Conectado!");
    Serial.print("IP: ");
    Serial.println(WiFi.localIP());
  } else {
    Serial.println("\nFalha ao conectar.");
    return;
  }

  Serial.println("Direc");
  direc();
  Serial.println("Anem");
  anem();
  Serial.println("DHT");
  sensorDHT();

  Serial.print("Direção: ");
  Serial.println(direcao);

  Serial.print("Velocidade do vento: ");
  Serial.print(speedwind);
  Serial.println("km/h");

  Serial.print("Milímetros de chuva: ");
  Serial.print(mm);
  Serial.println("mm");

  Serial.print("Umidade: ");
  Serial.print(h);
  Serial.println("%");
  Serial.print("Temperatura: ");
  Serial.print(t);
  Serial.println("°C ");
  Serial.print("Calor: ");
  Serial.print(hic);
  Serial.println("°C ");
  Serial.println("--------------------");

  // Crie uma mensagem JSON com os dados do sensor
  String payload = "{\"temperatura\":" + String(t) + ",\"humidade\":" + String(h) + ",\"calor\":" + String(hic) + ",\"direcao\":\"" + direcao + "\",\"velocidade do vento\":" + String(speedwind) + ",\"milimetros de chuva\":" + String(mm) + "}";


  String url = String(thingsboardServer) + "/api/v1/" + accessToken + "/telemetry";  // Crie a URL para enviar os dados para o ThingsBoard

  // Crie um cliente HTTP e envie os dados
  HTTPClient http;  
  http.begin(url);
  http.addHeader("Content-Type", "application/json");
  int httpResponseCode = http.POST(payload);

  // Verifique a resposta do servidor
  if (httpResponseCode > 0) {
    Serial.print("Codigo de Resposta: ");
    Serial.println(httpResponseCode);
  } else {
    Serial.print("Erro no envio, Codigo de Resposta: ");
    Serial.println(httpResponseCode);
  }

  http.end();

  // Após o envio dos dados, desabilita o WiFi
  WiFi.disconnect(true);
  WiFi.mode(WIFI_OFF);
  Serial.println("Desconectado.");
  
  Serial.flush(); 
  esp_deep_sleep_start();
}

void direc() {
  int reads[8] = {digitalRead(PIN1), digitalRead(PIN2), digitalRead(PIN3), digitalRead(PIN4), digitalRead(PIN5), digitalRead(PIN6), digitalRead(PIN7), digitalRead(PIN8)};
  const char* direcoes[8] = {"Norte", "Nordeste", "Leste", "Sudeste", "Sul", "Sudoeste", "Oeste", "Noroeste"};

  for (int i = 0; i < 8; i++) {
    if (reads[i] == 1) {
      direcao = direcoes[i];
      return;
    }
  }

  direcao = "erro";
}

void pluvi(){
  unsigned long currentPluviMillis = millis();

  if (currentPluviMillis - lastPluviTime >= debouncePluviDelay) {
    lastPluviTime = currentPluviMillis;
    ciclo++;
    mm += 1.729;
  }
}

void anem(){
  speedwind = 0;
  windspeed = 0;
  counter = 0;

  long startTime = millis();
  while (millis() < startTime + period) {
    int readAnem = digitalRead(ANEMPIN);  // Reading pin value

    if (readAnem == 1){
      counter++;
      delay(20);
      while (readAnem == 1) {
        readAnem = digitalRead(ANEMPIN);
        if (readAnem != 1){
          break;
        } else if (millis() >= startTime + period){
          break;
        }
      }
    }
  }

  RPM = ((counter) * 60) / (period / 1000); // Calculate revolutions per minute (RPM)

  speedwind = (((2 * pi * radius * RPM) / 60) / 1000) * 3.6; //Calcula velocidade do vento em km/h
}

void sensorDHT(){
  h = dht.readHumidity();
  t = dht.readTemperature();
  hic = dht.computeHeatIndex(t, h, false);
}

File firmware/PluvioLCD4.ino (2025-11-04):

#include <LiquidCrystal.h> //Inclui a biblioteca do LCD
 
LiquidCrystal lcd(12, 11, 5, 4, 3, 2); //Configura os pinos do Arduino para se comunicar com o LCD

// Constantes:
  const int REED = 6;              //The reed switch outputs to digital pin 9
 
  // Variáveis:
int val = 0;                    //Current value of reed switch

int old_val = 0;                //Old value of reed switch

int REEDCOUNT = 0;              //This is the variable that hold the count of switching

 // as variaveis a seguir sao do tipo long pois o tempo, medido em milissegundos,
 // rapidamente se tornara em um numero grande demais para ser armazenado em uma int.
 
 
 void setup() {
   // initializa o pino do switch como entrada
   pinMode (REED, INPUT_PULLUP); //This activates the internal pull up resistor

   // initializa a comunicaçao serial:
   Serial.begin(9600);
   digitalWrite(2,HIGH);
lcd.begin(16, 2); //Inicia o LCD com dimensões 16x2(Colunas x Linhas)
lcd.setCursor(0, 0); //Posiciona o cursor na primeira coluna(0) e na primeira linha(0) do LCD
lcd.print("Pulsos "); //Escreve no LCD "Olá Garagista!"
lcd.setCursor(0, 1); //Posiciona o cursor na primeira coluna(0) e na segunda linha(1) do LCD
lcd.print("Chuva "); //Escreve no LCD "LabdeGaragem"
 }
 
 void loop() {
   // ler o estado do switch pelo pino de entrada:
  val = digitalRead(REED);      //Read the status of the Reed swtich


 if ((val == LOW) && (old_val == HIGH)){    //Check to see if the status has changed

   delay(10);                   // Delay put in to deal with any "bouncing" in the switch.

   REEDCOUNT = REEDCOUNT + 1;   //Add 1 to the count of bucket tips

   old_val = val;              //Make the old value equal to the current value
       Serial.print("Medida de chuva (contagem): ");
       Serial.print(REEDCOUNT);//*0.2794); 
       Serial.println(" pulso");
       Serial.print("Medida de chuva (calculado): ");
       Serial.print(REEDCOUNT*0.25); 
       Serial.println(" mm");
       lcd.setCursor(8, 0); //Posiciona o cursor na décima quarta coluna(13) e na segunda linha(1) do LCD
       lcd.print(REEDCOUNT); //Escreve o valor atual da variável de contagem no LCD
       lcd.setCursor(8, 1); //Posiciona o cursor na décima quarta coluna(13) e na segunda linha(1) do LCD
       lcd.print(REEDCOUNT*0.25); //Escreve o valor atual da variável de contagem no LCD
       lcd.setCursor(14, 1); //Posiciona o cursor na primeira coluna(0) e na segunda linha(1) do LCD
       lcd.print("mm"); //Escreve no LCD "LabdeGaragem"
       } 
 
     else {

   old_val = val;              //If the status hasn't changed then do nothing

 }

}

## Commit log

2025-11-04 primeiro commit
    [EixoVelVento.stl, NucleoEstacao.stl, PeçaBaixaSuportePainelSolar.stl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]
2025-12-08 Fix image path for mounted station in README
    Updated image path in README.md to reflect new directory structure.
